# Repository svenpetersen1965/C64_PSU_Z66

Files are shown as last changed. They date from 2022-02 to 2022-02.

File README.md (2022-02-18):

# C64_PSU_Z66
This is a PSU for the Commodore C64 in the Kradex Z66 case. The goal of the development is a budget but capable and reliable PSU for the C64.

This repository contains a full documenation and all project files. The <a href="https://github.com/svenpetersen1965/C64_PSU_Z66/blob/main/Rev.%201/PDF/C64PSU-Z66_Rev1.pdf">documentation</a> can be found in the pdf subdirectory. Read it, please. 

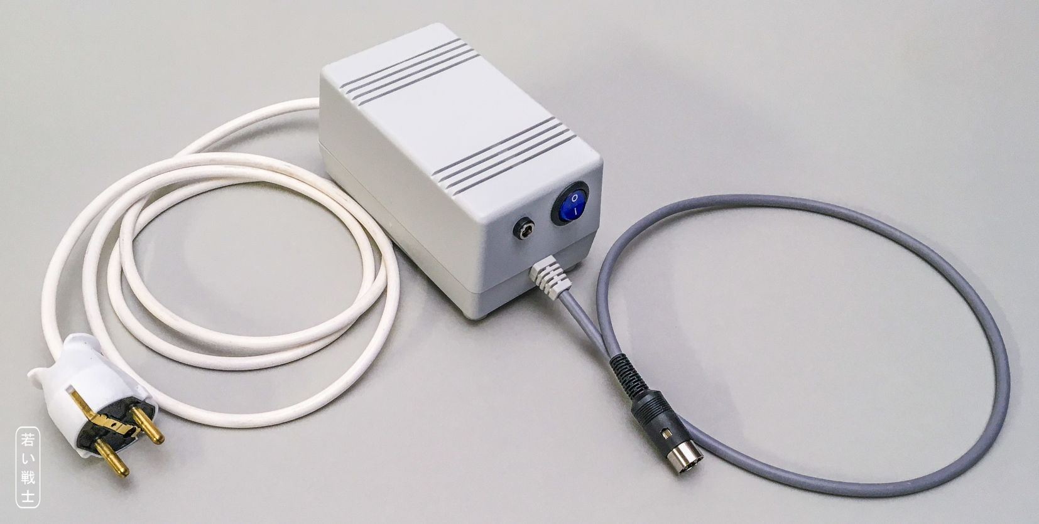
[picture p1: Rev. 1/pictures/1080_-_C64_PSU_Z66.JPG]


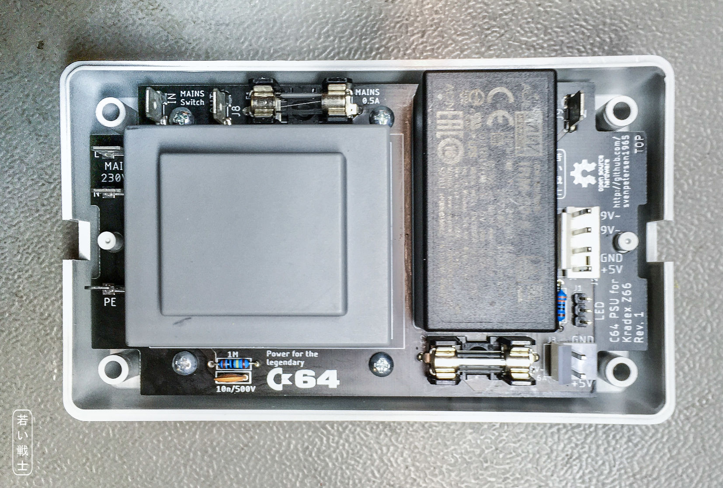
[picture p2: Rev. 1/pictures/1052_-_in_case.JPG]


Learn more about cable making: Please visit my <a href="http://tech.guitarsite.de/cable_making.html">website</a>.

The BOM value of the PSU is 42.16€ (as of February 2022).

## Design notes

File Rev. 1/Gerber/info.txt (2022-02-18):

       
       Board: C64_PSU_Z66
       Rev.:  1
  
       Files:
       ======
  
       All Gerber files are generated in extended gerber format (RS274X)
       *.TOP        : Film top copper
       *.BOT        :  -"- bottom copper
       *.STC        :  -"- top soldermask 
       *.STS        :  -"- bottom soldermask
       *.PLC        :  -"- silk screen top
       *.MIL        : Millings 
       *.DK         : Drills plated Through (Excellon)
       *.NDK        : Drills not plated Through (Excellon)
       *.OUT        : Board outline

       Board Size:
       ===========
       Length     :   123.5 mm
       Width      :   70.0 mm
       Thickness  :   1.6 mm
       Material   :   FR 4
       Copper     :   35 um
       Surface    :   HASL
       
       Remarks:
       ========

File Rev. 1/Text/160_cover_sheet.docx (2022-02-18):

Project Documentation

Commodore C64 PSU for the Kradex Z66 Case

Project number: 160

Revision: 1

Date: 08.02.2022

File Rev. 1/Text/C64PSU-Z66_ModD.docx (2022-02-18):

Commodore C64 PSU for the Kradex Z66 Case Rev. 1

Module Description

# Introduction

The goal of this development is a budget 230V PSU for the Commodore C64 (and VIC-20CR) in a budget case (Kradex Z66) with easy to do cut outs. It is based on a transformer for the 9VAC and an AC/DC module for the +5VDC.


Figure 1: C64 PSU in the Z66 case

There are two options for the transformer:

- BREVE TUFVASSONS: TEZ10/D/9V (10VA/1A fuse)
- Block: VC16/1/9 (16VA/1.6A fuse, not recommended)

It is recommended to use the (cheaper) 10VA type. Since transformers are not regulated, the nominal output voltage is reached at nominal load, below that load, the output voltage is higher. Usually, it is no problem to use a 16VA transformer with the C64, but some of the (oldest) 5 pin/ASSY 326298 boards do not have a heat sink on the linear 5V regulator (7805). Due to the higher output voltage of the transformer, the input of the 7805 is also higher and the regulator tends to overheat (which will first cause video problems). With all other ASSY numbers, even an 18VA transformer does not cause any trouble. The VIC-20 CR (DIN power jack) works well with both transformers. The fuse has to be different for each of the two transformers.

Further on, there are two options for the AC/DC module:

- Mean Well: MPM-10-5 (2A/10W)
- Mean Well: IRM-20-5 (4A/20W)

Both modules have a pretty similar and work well with the C64. The 20W model allows to additionally power a Raspberry Pi/Pi1541 through a barrel connector. The 10W AC/DC module allows to power an additional device like the retroTINK HDMI converter. A USB jack can be installed for this purpose.

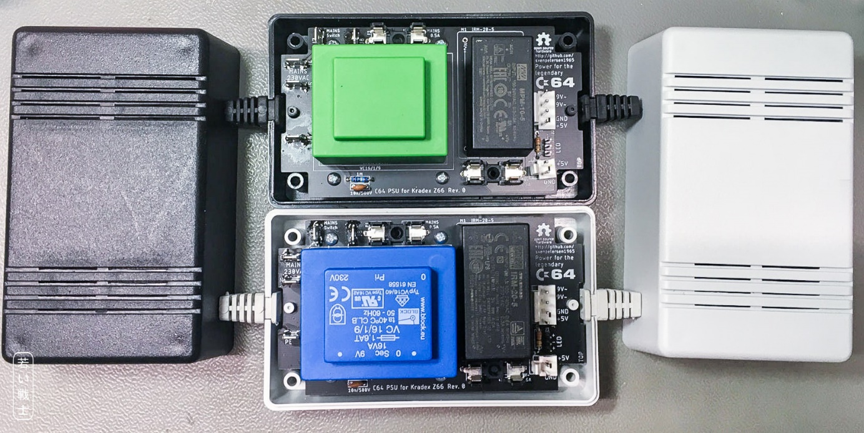
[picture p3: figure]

Figure 2: Both versions of transformer and AC/DC-module (Rev. 0)

# Functional Description

The PSU generates +5VDC and 9VAC from the mains voltage of 230V. The +5VDC is the out voltage of an AC/DC converter M1 or M2. The maximum output current depends on the chosen model of this converter. 2A are sufficient (the original PSU generated max. 1.5A). M1 and M2 have wide range inputs and would be capable of 85VAC to 264VAC mains voltage. The 9VAC are generated with a transformer (TR1 or TR2). Thus, the mains voltage should be close to the 230V nominal primary voltage of the transformer.

The protective earth (PE) of the mains cable is connected to GND via an RC-combination (1MΩ in parallel with 10nF/500V). This is to prevent any mains voltage coupled via a stray capacitance between primary and secondary, which is a very common thing with AC/DC converters and switch mode PSUs in general. It also cancels the coupled mains voltage of any PSU in the system, like the power supply of the monitor, the HDMI converter or a Pi1541 disk drive emulator. It is not (yet) a common feature of Commodore replacement PSUs and definitely worth the investment for a fully wired mains connection and the R and the C.

The PSU has an input fuse (500mA, slow blow), a mains power switch (illuminated). The transformer has an output fuse (1A or 1.6A depending on the model).

Since the AC/DC modules have a short circuit, over voltage, overload and over temperature protection, there is no fuse for the +5V. Further, there should be as little voltage drop between the module and the computer. The 5V is pretty accurate (while the original PSUs have a no-load output voltage of about 5.2V to 5.3V). The voltage-drop over a fuse is quite high (over 100mV, depending on the value of the fuse).

Also, the output cable should be as short as possible (50cm to 70cm are recommended).

The mains switch has an input, an output and the neutral (N). Neutral is only required for illuminated mains switches. The N spade connector on the switch is usually colored differently (e.g. brass, while the other two are silver coated).

There is a connector for a power LED. With an illuminated mains switch, it is not required. The 330Ω resistor R1 is sufficient for red, yellow or green LEDs. Blue and white LEDs are usually “bright enough” with this value. R1 is not required, if no power LED is connected.

Since both AC/DC module have a soft start feature, the 5VDC are slightly delayed against the 9VAC. I have never experienced any problem when the C64 was switched on before the PSU was switched on, the recommended power up sequence is PSU first, C64 second.

# Connectors

## Spade connectors

There are 6 spade connectors (6.3x0.8mm) on the board, which are all connected to mains voltage.

Connector | Function
J4 | 230V mains L (hot)
J5 | 230V mains N (neutral)
J6 | PE (protective earth)
J7 | Mains switch input lead
J8 | Mains switch output lead
J9 | Mains switch N (neutral)

## J1 – Power LED

- Pin header, 1x3 circuits, 2.54mm (0.1”) pitch
- Crimp housing: Dupont crimp housing
- Dupont crimp terminals

It is possible to use a widely available (Ebay, AliExpress etc.) Dupont cable, which can be cut and soldered to the LED.

Pin | Signal
1 | LED +
2 | LED -
3 | LED +

The pin out of this power LED connector is the same like in a C64 and VIC-20.

## J2 – C64 Power Connector

- Molex KK 396 Header, Vertical, Friction Lock, 4 Circuits, Tin (Sn) Plating: P/N 0026604040
- KK 3.96mm Crimp Terminal Housing, Friction Ramp, 4 Circuits, Natural: P/N 09503041
- KK 396 Crimp Terminal 2478, 18-24 AWG, Bag, Brass Tin (Sn): P/N 08500106.

Pin | Signal
1 | +5V
2 | GND
3 | 9VAC2
4 | 9VAC1

## J3 – Auxiliary +5V Connector

- Molex KK 396 Header, Vertical, Friction Lock, 2 Circuits, Tin (Sn) Plating: P/N 0026604020
- KK 3.96mm Crimp Terminal Housing, Friction Ramp, 2 Circuits, Natural: P/N 09503021
- KK 396 Crimp Terminal 2478, 18-24 AWG, Bag, Brass Tin (Sn): P/N 08500106.

Pin | Signal
1 | +5V
2 | GND

## Note

If you want to find a cheaper alternative for the Molex KK 3.96 connector series, the search term on Ali Express is “CH3.96”. Do not mix Molex crimp terminals with CH3.96 housings and vice versa. They do not fit well to each other.

A suitable crimp tool for this kind of connector is e.g., the Engineer PA-20 (1.9/2.3 for wire/insulation crimp) or the IWISS IWS-2820 (the cheaper one - 1.9/2.2 for wire/insulation crimp). Also, the IWISS SN-28B crimp tool produces decent crimps (22-20 notch).

The spade/FastOn connectors require a crimp tool for insulated connectors. The color of the insulation is not matter of taste. It marks the suitable wire gauges. With an AWG20/0.75mm² cable, you need a red insulation (0.5mm²-1.5mm²/AWG21-16). The crimp tool has colored dots below the dedicated notch.

# Cable Making

## Lengths

Cable | Length | Note
Mains | 2 meters, up to your taste | Strip off the (outer) jacket: 8cm, 3xAWG20/0.75mm²
Switch L (in) | 16cm | Brown AWG20/0.75mm²
Switch L (out) | 15cm | brown (or black)
Switch N | 9cm | blue
5V auxiliary | 8cm | AWG20, red and black
Power LED | 10cm | AWG24/0.25mm², red and black
Output | 50cm – 70cm | Strip off the mantle: 6cm, 4xAWG20/0.75mm²

## Mains cable

The mains cable is matter of how long you want it to be. There is no critical length within the range of a few meters. Rather make the mains cable longer and the output cable as short as possible.

The cable jacket (outer insulation) has to be stripped off approximately 8cm. The wire insulation should be stripped off 5mm.

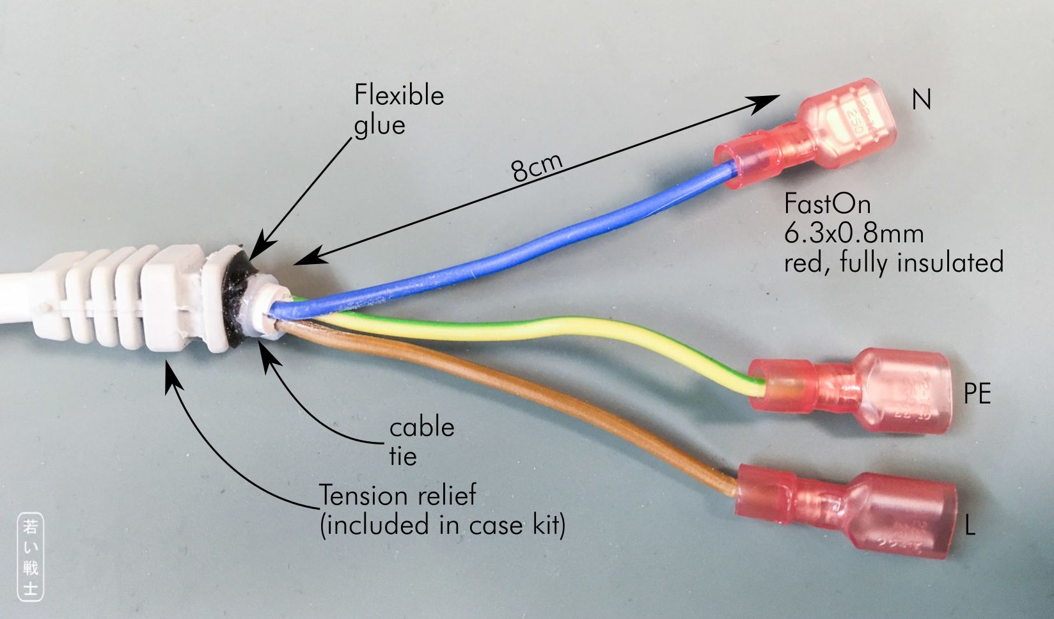
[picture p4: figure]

Figure 3: Mains cable

The case comes with two tension reliefs, one for the input (mains) cable and one for the output cable. This will not hold the cable securely. So additional actions have to be taken. A (small) cable tie works pretty well here. Further, gluing the cable into the tension relief with a flexible (silicon) glue is recommended. An epoxy-based glue does not work.

The FastOn crimps should be carried out well and the crimp needs to be tested (pull test). Better order more FastOn connectors than required in the BOM.

The colors of the (inner) wires are (most common):

Wire | Function
brown | Hot (L)
blue | Neutral (N)
yellow-green | Protective Earth (PE)

Note: if you are not familiar with this already, you should probably not be building this power supply.

## Mains Switch

The mains switch is preferably a round switch with a 20mm mounting hole. Illuminated switches require a 3rd (N) lead, the input and the output tap should not be confused, so the light goes off, when the switch is off (ion case you do not require a night light). Non-illuminated switches only require two leads and are not directional.

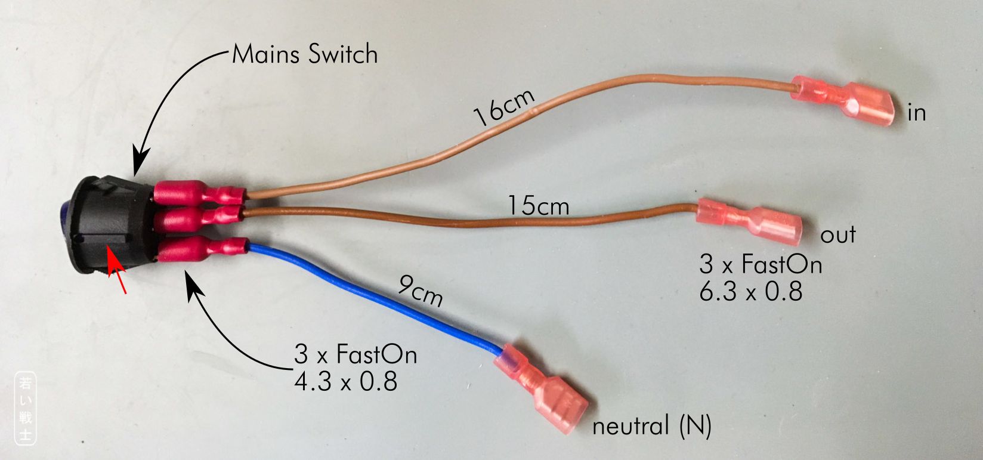
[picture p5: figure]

Figure 4: Mains switch

The anti-twist protection is marked with a red arrow. The N tap is usually marked with a different color. Again, the FastOn crimps should be carried out well and each crimp should be tested.

## Output Cable

The colors of the shown output cable comply with IEC 60757. This does not really matter, but you should choose them in a way, that it can be soldered to the DIN-connector comfortably.

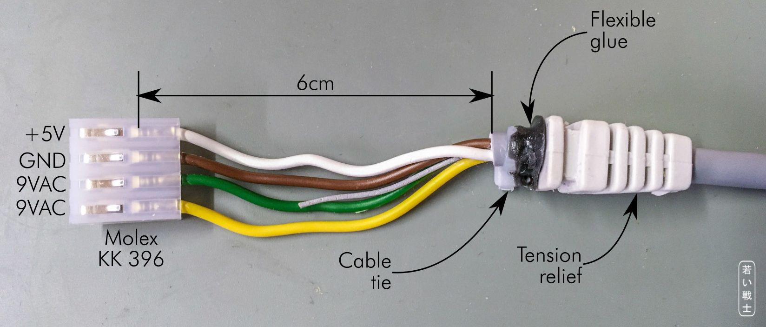
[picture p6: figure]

Figure 5: The output cable

Pin | Function | Color
1 | +5V | white
2 | GND | brown
3 | 9VAC (1) | green
4 | 9VAC (2) | yellow

The other end of the cable is the DIN connector. Make sure, that you do not forget to install the tension relief and the insolation sleeve of the DIN-jack, before you start soldering the cable to the connector. Millions of cables had to be soldered a 2nd time, because one of these items were forgotten to install (in the proper orientation).

There are several methods to solder a DIN-connector, some stick the connector insert into a potato (rich people use an avocado instead). I prefer using the helping hand for the first solder joint, the remaining solder joints can be performed without, since the insert is already attached to the cable. Do not tin the wire strands before inserting them into the solder cups of the pins. The connectors with half solder cups are easiest to solder. Flux is a great invention and definitely helpful when soldering the DIN connector.

The following table shows the pin out of the C64 (and VIC-20 CR).

C64 Power Jack | Pin | Voltage
| 1 | -
| 2 | GND
| 3 | -
| 4 | -
| 5 | +5V
| 6 | 9VAC(1)
| 7 | 9VAC(2)

Table 1: Power jack of the C64

The 9VAC leads can be swapped if required. It is AC, so the polarity does not matter.

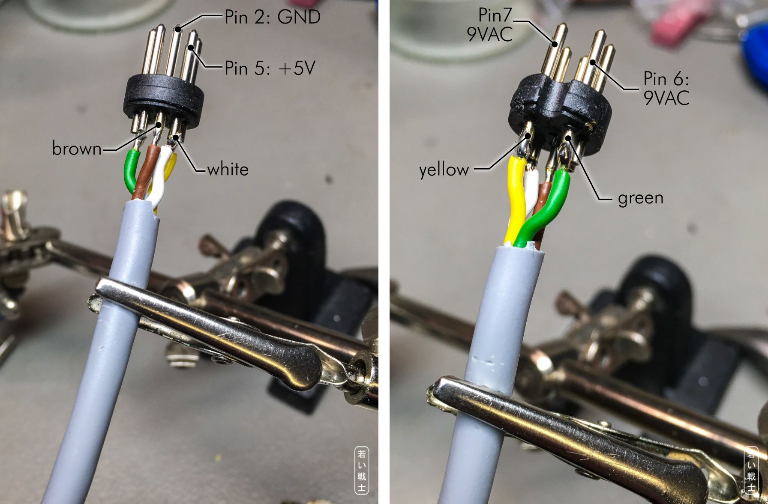
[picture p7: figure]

Figure 6: Soldering the DIN-plug (output cable)

## Auxiliary 5V cable (optional)

The auxiliary 5V cable is optional. It makes use of the power reserve of the AC/DC module.

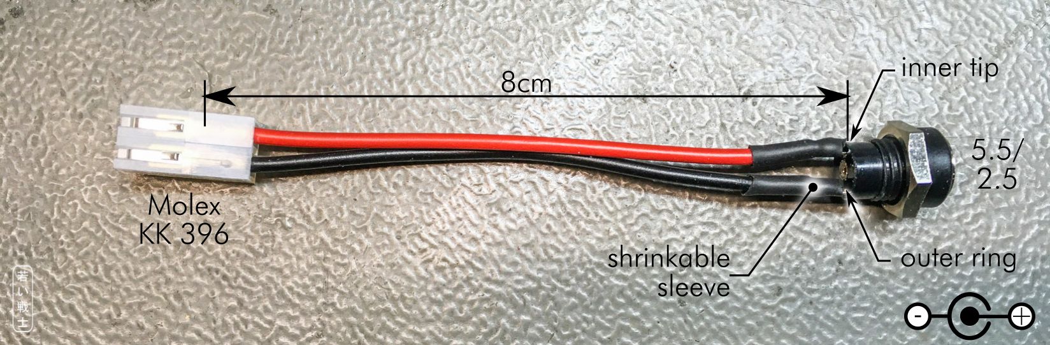
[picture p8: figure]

Figure 7: Auxiliary 5V cable (optional)

It might be good not to install the crimp housing before the cable is installed in the case. The crimp terminals can pass the drill in the case, the housing of the connector does not. The terminals can be removed from the housing, but it is better to avoid this work.

## USB-Port (optional)

Alternatively to the barrel jack, a USB jack can be installed to provide auxiliary 5V. This is the choice, if an additional device with a (micro) USB port should be powered. The USB connector is harvested from a slot bracket.

The +5V of the USB-cable is usually a red wire, the GND is the black wire. The data wires are white and green.

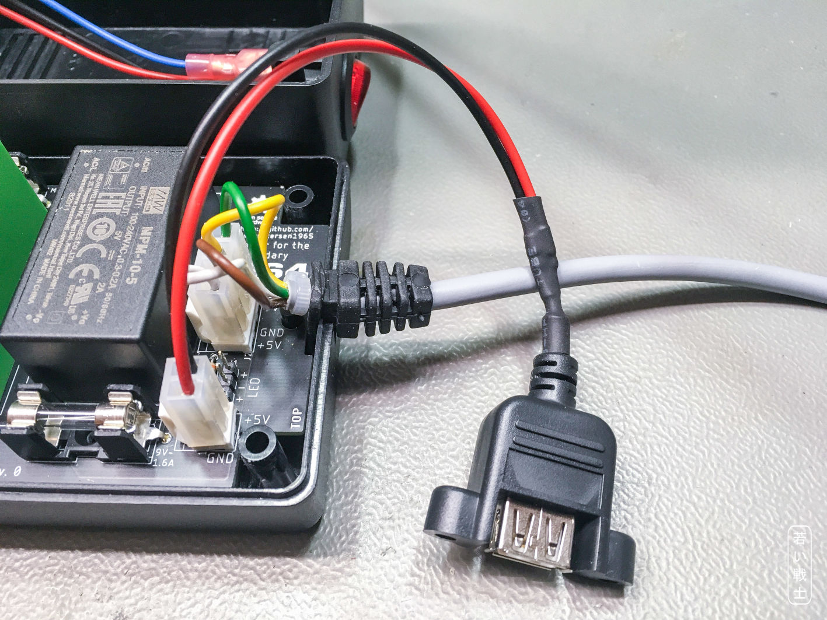
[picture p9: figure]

Figure 8: USB-Port (optional)

The cable making is a bit harder - the cutout is more complicated, too. It is a matter of taste, if this more complicated cable is installed or a standard USB cable is modified with a barrel plug to power a device like mentioned before.

## LED-Cable (optional)

The power LED is optional. Usually, it is not required in case the mains switch is illuminated.

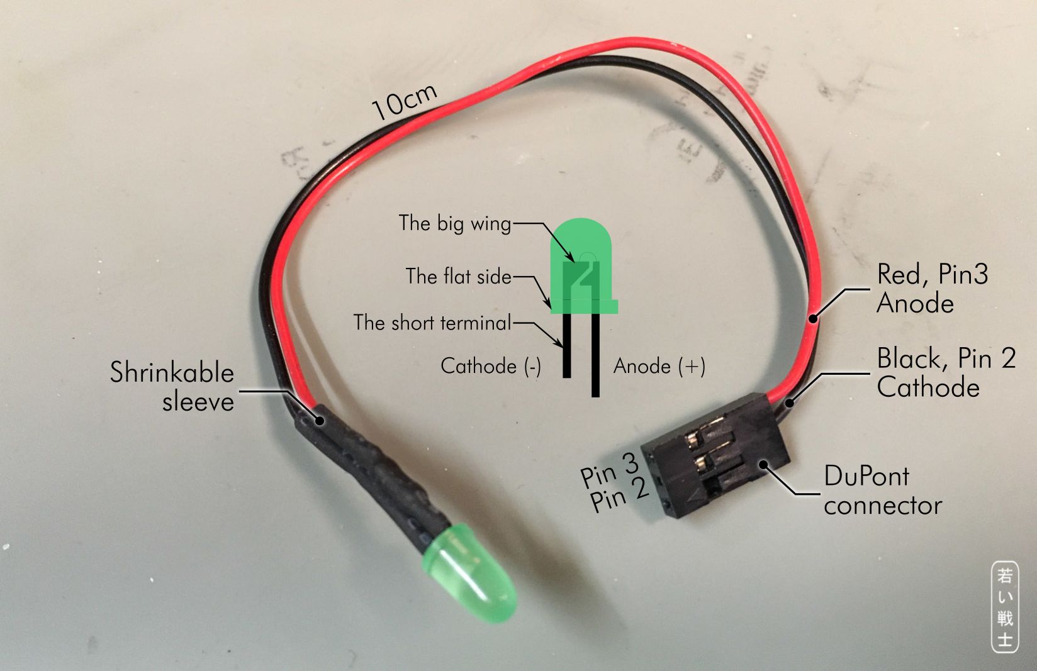
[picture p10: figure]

Figure 9: Power LED (optional)

Note:
For crimping the DuPont terminal, the Engineer PA-20 (1.6/1.6 for wire/insulation crimp) or the IWISS IWS-2820 (the cheaper one - 1.6/1.6 for wire/insulation crimp) is a working choice. The IWISS SN-025 might be the most suitable tool.

# Installation in the Z66 Case

There are only a few cutouts in the case.

1. Mains switch
2. Auxiliary +5V/barrel connector (optional)
3. USB port for auxiliary 5V (optional)
4. Power LED

The mains switch is primarily a 20mm drill and a notch for the anti-twist protection. The auxiliary 5V barrel connector is just a round hole. The diameter depends on the type of connector used for this. It can be measured with a caliper.

There are 1:1 scaled drawings, which can be printed out (in the original scale), cut out, then positioned and fixed to the case. The centers of the holes can be marked with a needle (after that, with a center punch). Also, the corners of the anti-twist notch of the mains connector.

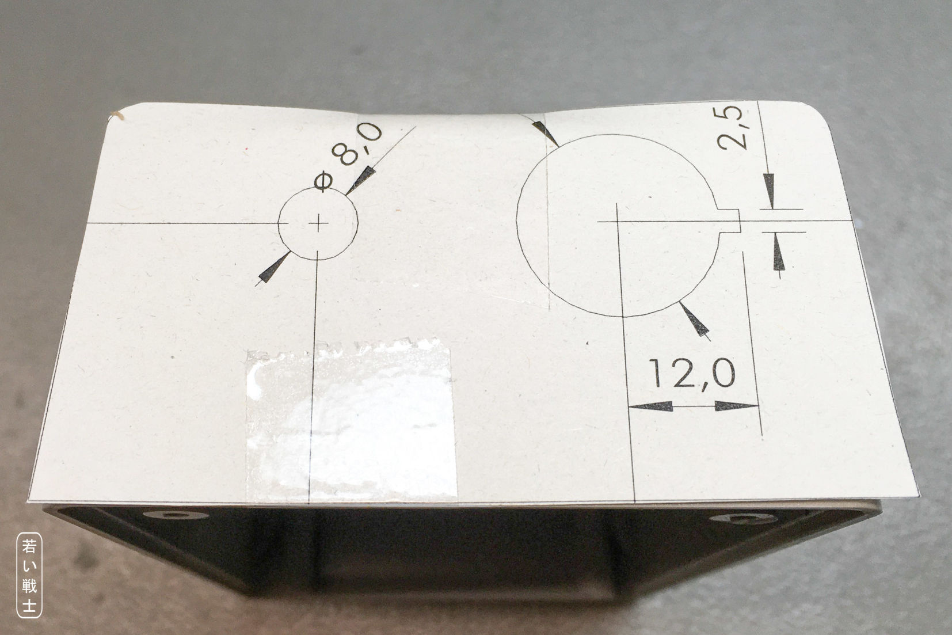
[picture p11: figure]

Figure 10: Marking the case with the drawing

The cutout drawing fits better on the case, than it looks in Figure 10, the appearance is matter of the used lens and the proximity. An accuracy of about +/- 0.5mm for the positioning of the paper is suitable. The center of the holes and the corners of the notch can be marked with a needle, first. A center punch only might not the accurate enough.

The 20mm hole for the mains switch is first started with a 4mm drill, which is the smallest diameter of my step drill. Just drill this with a normal drill. Then use the step drill to obtain a 20mm hole.

The notch for the anti-twist protection is then filed with a small square file. Do not file the notch too deep, it would become visible even after the switch is installed.

The diameter of the hole for the barrel connector is not necessarily 8mm, it depends on the connector type.

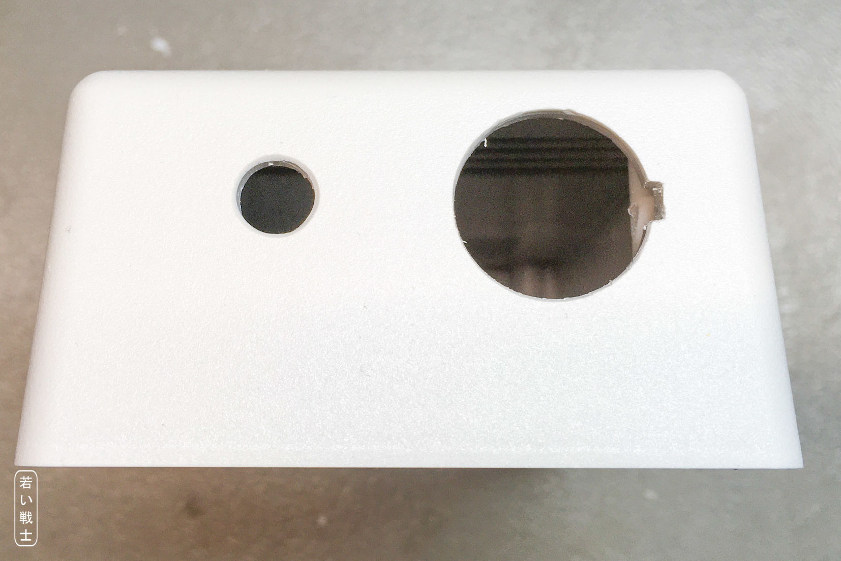
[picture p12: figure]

Figure 11: The top shell after drilling

If a power LED is desired, a hole, that fits the LED holder needs to be drilled. The top side might be a good place, a central position close to the front edge is suggested.

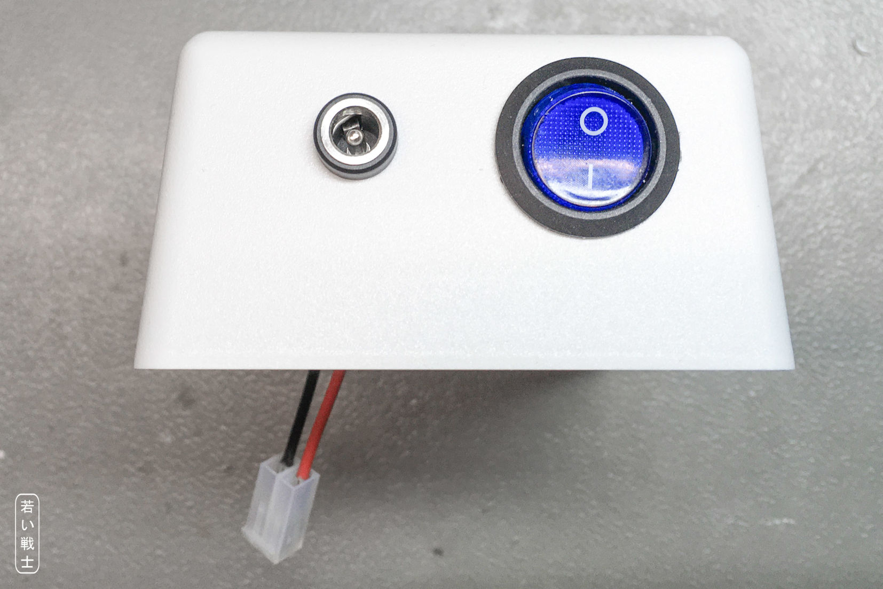
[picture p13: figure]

Figure 12: The top shell with the switch and the auxiliary barrel connector installed

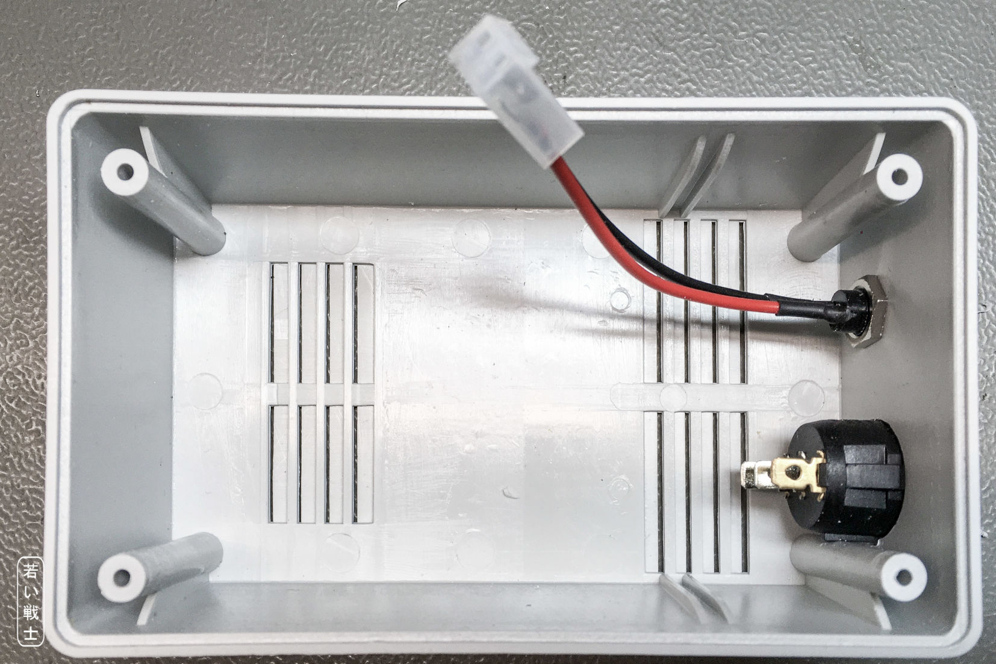
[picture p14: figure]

Figure 13: Top shell, bottom view

There is another drawing for the USB port cutout, which can be used as a template. The connector is positioned in a way, that it fits above the AC/DC module.

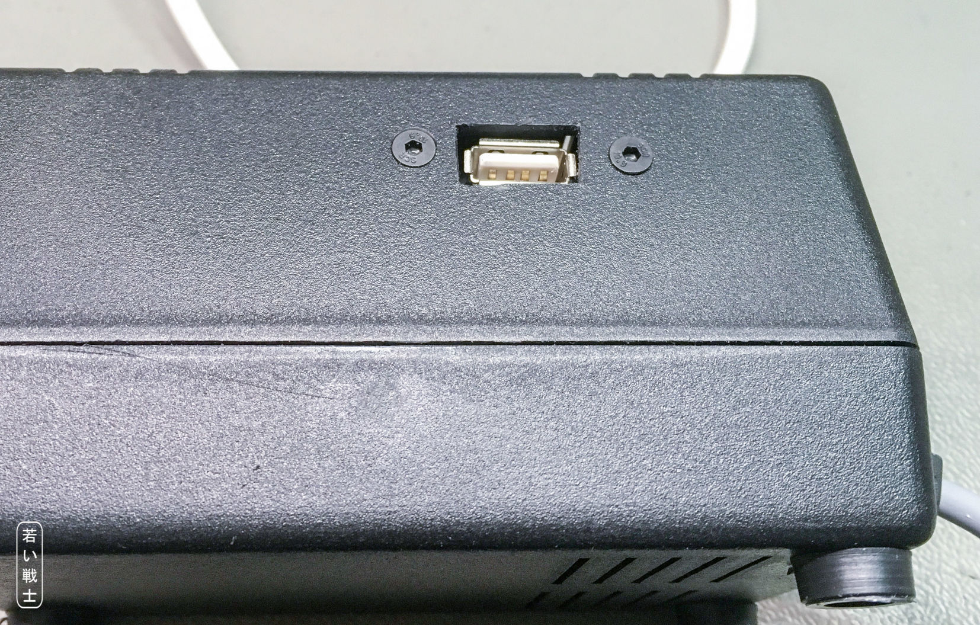
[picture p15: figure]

Figure 14: The USB port on the left side of the top shell

The USB connector is screwed to the top shell with two screws (M3). In Figure 14 these are countersunk. Black screws might fit better to a black case, for a light grey case, normal coated screws are a good choice.

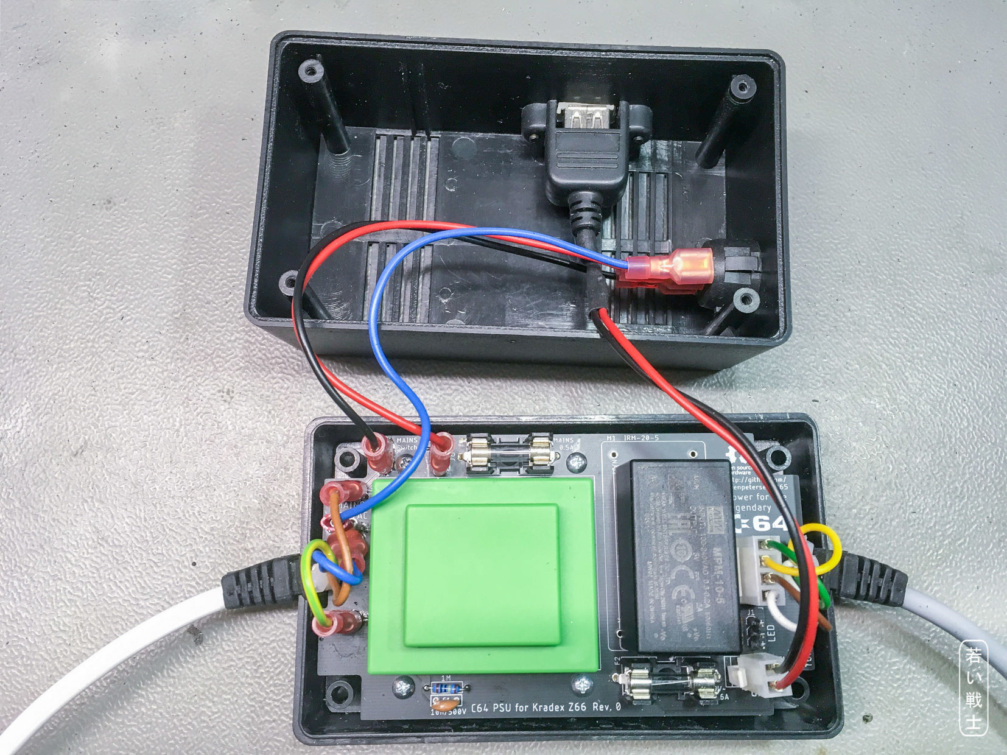
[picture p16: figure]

Figure 15: USB cable installed on a Rev. 0 board

## Testing

Before connected to the real computer, it is strictly advised to check the polarity of the +5V and GND on the DIN-Connector. Refer to Table 1: Power jack of the C64. A good way for testing the DIN connector is to connect it to a DIN jack.

In case you need to test C64 PSUs more often, this is a good thing to have.

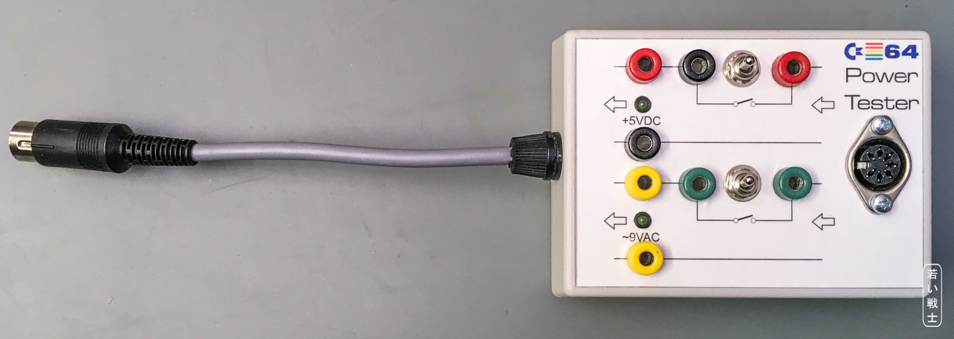
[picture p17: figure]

Figure 16: The C64 PSU tester

It is of course not required to have such a test device for building one power supply. The pictures are just put in here as an inspiration. The 4mm lab jacks allow to connect multimeters and load resistors (or an electronic load, if you have one).

Some of the old PSUs have the +5V connected to Pin 4, which is the reason for the 2nd red wire in Figure 17.

The LED for the 9VAC require an anti parallel protection diode. They are not capable of much more than 4V reverse voltage and would get destroyed by the AC.

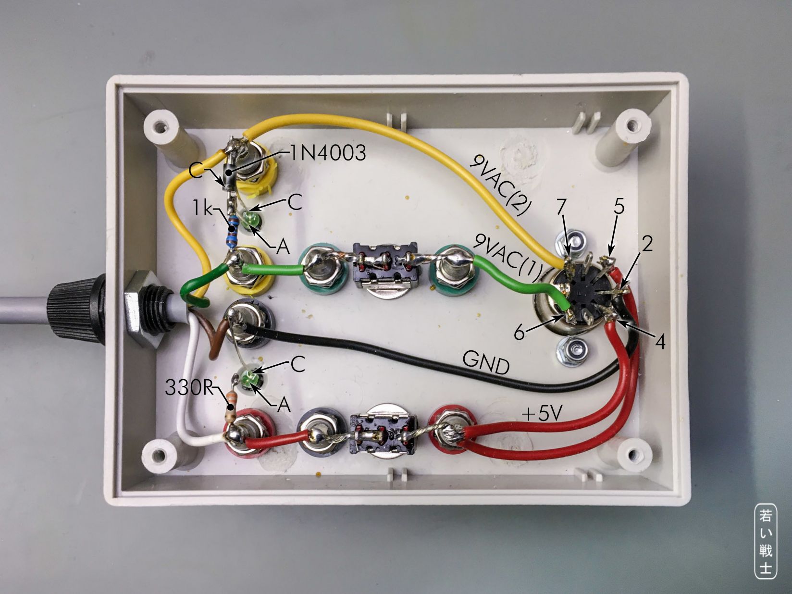
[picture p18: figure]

Figure 17: The C64 PSU tester (inside)

# Dimensions

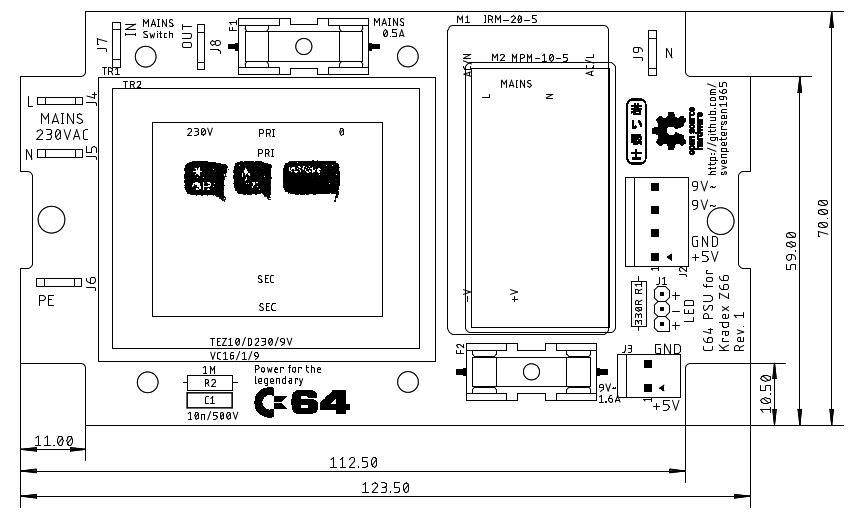
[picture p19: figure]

Figure 18: Dimensions of the PCB (not scaled)

# Revision History

## Rev. 0

- Fully functional prototype

## Rev. 1

- FastOn J9 added as N connector for illuminated power switches

C64PSU-Z66_ModD.docx 18.02.2022 20:13 Drafted by Sven Petersen Page 2 of 2 Doc.-No.: 160-6-01-01

C64PSU-Z66_ModD.docx 18.02.2022 20:13 Drafted by Sven Petersen Page 1 of 1 Doc.-No.: 000-6-00-00

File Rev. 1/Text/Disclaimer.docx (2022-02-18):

Disclaimer

Working with mains voltages can be harmful and cause death. Do not connect this PCB to mains (230VAC) unless you are trained in doing so and know the required safety regulations.

This PSU is a prototype, it is not certified in any way and might only be used as a prototype under laboratory conditions. Usage is at own risk. Do not leave unattended while powered on or connected to mains.

The PSU is designed to be installed in a plastic case. A 3 prong mains connector (with protective earth PE is recommended, though).

The documentation is drafted to the best of my knowledge. The creator is not liable for the accuracy and completeness.

Disclaimer.docx 08.02.2022 17:45 Erstellt von Sven Petersen Seite 2 von 2 Dok.-Nr.: 000-8-00-00

Disclaimer.docx 08.02.2022 17:45 Drafted by Sven Petersen Page 1 of 1

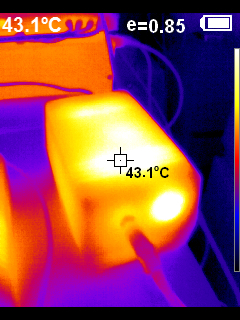
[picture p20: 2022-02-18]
Rev. 1/pictures/20220217-194722_FLIR_outside_9h.jpg

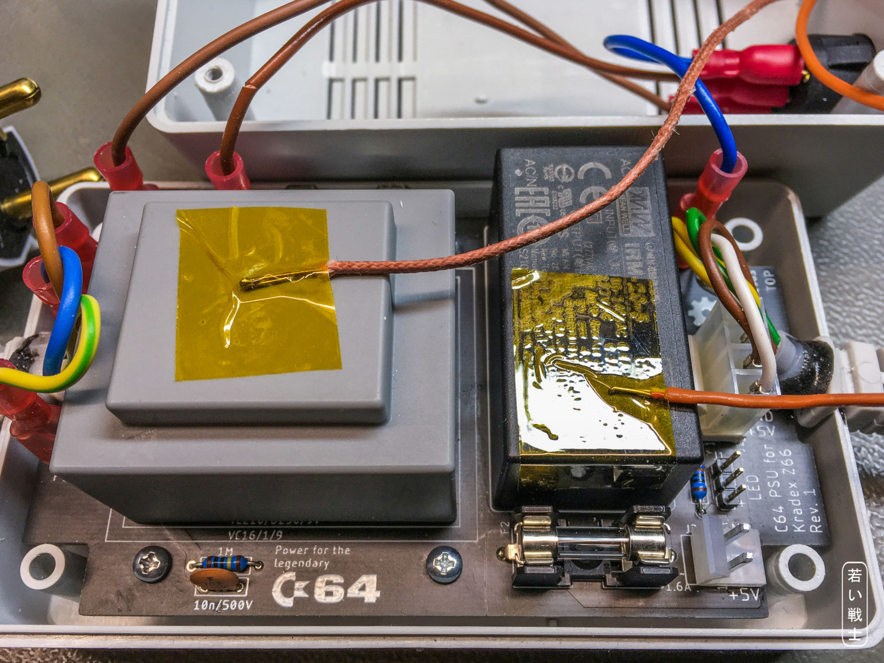
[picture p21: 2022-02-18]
Rev. 1/pictures/1163_-_thermal_1st_configuration.JPG

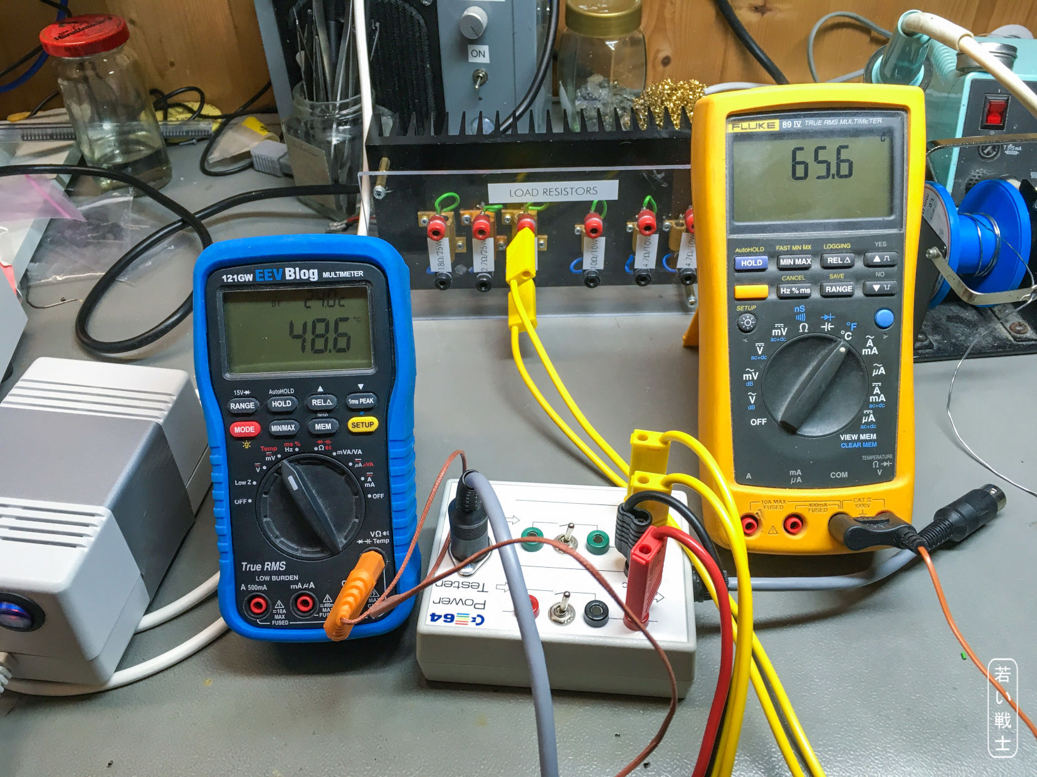
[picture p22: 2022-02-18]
Rev. 1/pictures/1185_-_thermal_final_reading_10VA.JPG

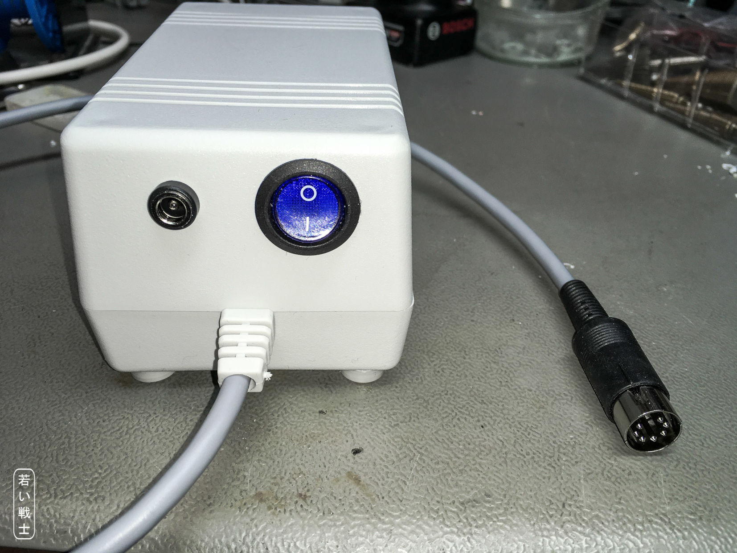
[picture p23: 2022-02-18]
Rev. 1/pictures/1065_-_front_view.JPG

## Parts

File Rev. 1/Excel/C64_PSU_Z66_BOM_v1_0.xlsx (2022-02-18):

C64 PSU "Z66" Rev. 1
Bill of Material Rev. 1.0
Pos. | Qty | Value | Footprint | Ref.-No. | Comment
1 | 1 | 160-2-01-01 | 2 Layer | PCB Rev. 1 | 2 layer, Cu 35µ, HASL, 123.5 x 70.0mm, 1.6mm FR4
2 | 6 | 6.3 x 0.8 | FLA6,3 | J4, J5, J6, J7, J8, J9 | Spade connector f. PCB, e.g. Reichelt VT FS-P 6,35
3 | 1 | Pin header 1x3, 2.54mm | 1X03 | J1 | e.g. MPE Garry 087-1-003, Reichelt MPE 087-1-003
4 | 1 | dupont housing, 3p |  | (J1) | ebay, AliExpress or other (optional: for power LED)
5 | 2 | dupont terminals, female |  | (J1) | ebay, AliExpress or other (optional: for power LED)
6 | 1 | Power LED + LED holder |  | (J1) | red, yellow, green, blue (optional)
7 | 1 | 26604020 | SPOX_3.96_2P | J3 | optional (+5V tap): Molex SPOX, e.G. Reichelt: MOLEX 26604020, tme.eu: MX-26-60-4020
8 | 1 | 09503021 |  | (J3) | crimp housing, optional (for +5V tap): Molex. E.g. Reichelt: MOLEX 9503021, tme.eu: MX-2139-2A
9 | 2 | 08500106 |  | (J3) | crimp terminal, optional (for +5V tap), Molex. E.g. Reichelt: MOLEX 08500106, tme.eu: MX-2478-1-P913L (= 10 pack)
10 | 1 | 26604040 | SPOX_3.96_4P | J2 | Molex SPOX, e.G. Reichelt: MOLEX 26604040, tme.eu: MX-26-60-4040
11 | 1 | 09503041 |  | (J2) | crimp housing: Molex. E.g. Reichelt: MOLEX 9503041, tme.eu: MX-2139-4A
12 | 4 | 08500106 |  | (J2) | crimp terminal, Molex. E.g. Reichelt: MOLEX 08500106, tme.eu: MX-2478-1-P913L (= 10 pack)
13 | 2 | 0031.8211 | 318211 | F1, F2 | Schurter fuse holder (5x20mm). E.g. Reichelt: PL OGN-25, tme.eu: 0031.8211
14 | 1 | 0.5A slow blow | 20x5mm | (F1) | Mains fuse
15 | 1 | 1.6A slow blow | 20x5mm | (F2) | option: Fuse for 9VAC (for VC16/1/9 transformer)
16 | 1 | 1.0A slow blow | 20x5mm | (F2) | option: Fuse for 9VAC (for TEZ10/D230/9V transformer)
17 | 1 | 10n/500V | C-5 | C1 | Ceramic Cap, 500V, pitch 5mm, Reichelt: KERKO-500 10N, tme.eu: CCH-10K (=10 pack)
18 | 1 | 1M | R-10 | R2 | Resistor, metal film, 5% or better, 0,6W
19 | 1 | 330R | R-10 | R1 | Resistor, metal film, 5% or better, 0,6W
20 | 1 | IRM-20-5 | IRM-5-20 | M1 | Mean Well. Reichelt IRM-20-5, tme.eu: IRM-20-5 (4A)
21 | 1 | MPM-10-5 | MPM10 | M2 | alternative for M1: Mean Well. Tme.eu: MPM-10-5 (2A)
22 | 1 | TEZ10/D230/9V | TEZ10 | TR2 | BREVE TUFVASSONS transformer, alternative for TR1, tme.eu: TEZ10/D/9V. Recommended type.
23 | 1 | VC16/1/9 | VC16/1/9 | TR1 | alternative for TR2: BLOCK transformer, Reichelt: EI 54/18,8 109 not recommended!
24 | 10cm | AWG24/0.25mm², red |  |  | Cable for Power LED (option)
25 | 10cm | AWG24/0.25mm², black |  |  | Cable for Power LED (option)
26 | 3cm | 2.4/1.2mm |  |  | shrinkable sleve, shrink ration 1:2 (power LED)
27 | 10cm | AWG21/0.5mm², red |  |  | Cable for +5V tap (option)
28 | 10cm | AWG21/0.5mm², black |  |  | Cable for +5V tap (option)
29 | 1 | Connector (barrel jack, 5.5/2.5) |  |  | Connector for +5V tap (option), e.g. Reichelt: HEBL 25
30 | 1 | mains cable, 3x0.75mm² |  |  | Mains cable (3 wire recommended), AWG 20
31 | 1 | MAS 70S |  |  | Hirschmann DIN plug 7pin, 262°. Reichelt: MAS 70S, tme.eu: MAS70SGR. Example for C64 power plug
32 | 0.5m | 4x0.5mm² |  | (J2) | Cable for output voltages. 4xAWG21
33 | 6 | 2-520184-2 |  | (J4), (J5), (J6), (J7), (J8), (J9) | TE connectivity, tme.eu: 2-520184-2 or Reichelt RND 465-00067. Example for 6.3 x 0.8 spade terminals, red, fully isolated. Required to connect to the mains connector and switch.
34 | 3 | FastOn connector 4.8x0.8, red, fully isolated |  |  | FastOn for power switch
34 | 30cm | AWG20/0.75mm², black |  |  | Cable for Power Switch
35 | 1 | 1858.1103 |  |  | option for rectangular Power switch: Marquardt 1858.1103, Reichelt: WIPPE 1858.1103, tme.eu: 1858.1103 or other
36 | 1 | R13112BBR3 |  |  | Recommended Power switch (round, 20mm): Bulgin, tme.eu: AE-R13112BNAA, Reichelt: WS R13-112 BNAB
37 | 1 | Kradex Z66 |  |  | Kradex Case, tme.eu. Black: Z66-ABS, Grey: Z66J-ABS
38 | 4 | screws C2.9x6.5mm |  |  | self tapping screws, e.g. DIN 7981
39 | 2 | small cable ties |  |  | e.g. 102x2.5mm (Reichelt KAB 100-2,5)

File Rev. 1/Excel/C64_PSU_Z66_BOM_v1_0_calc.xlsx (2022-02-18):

C64 PSU "Z66" Rev. 1
Bill of Material Rev. 1.0
Pos. | Qty | Value | €/ea | € (total) | Comment
1 | 1 | 160-2-01-01 | 2.00 € | 2.00 € | 2 layer, Cu 35µ, HASL, 123.5 x 70.0mm, 1.6mm FR4
2 | 6 | 6.3 x 0.8 | 0.05 € | 0.30 € | Spade connector f. PCB, e.g. Reichelt RND 465-00018 (100ea)
3 | 1 | pin header 1x3, 2.54mm | 0.08 € | 0.08 € | ebay, AliExpress or other (optional: for power LED)
4 | 1 | dupont housing, 3p | 0.10 € | 0.10 € | ebay, AliExpress or other (optional: for power LED)
5 | 2 | dupont terminals, female | 0.05 € | 0.10 € | ebay, AliExpress or other (optional: for power LED)
6 | 1 | Power LED + LED holder | 0.45 € | 0.45 € | red, yellow, green, blue (optional)
7 | 1 | 26604020 | 0.36 € | 0.36 € | optional (+5V tap): Molex SPOX, e.G. Reichelt: MOLEX 26604020, tme.eu: MX-26-60-4020
8 | 1 | 09503021 | 0.14 € | 0.14 € | crimp housing, optional (for +5V tap): Molex. E.g. Reichelt: MOLEX 9503021, tme.eu: MX-2139-2A
9 | 2 | 08500106 | 0.11 € | 0.22 € | crimp terminal, optional (for +5V tap), Molex. E.g. Reichelt: MOLEX 08500106, tme.eu: MX-2478-1-P913L (= 10 pack)
10 | 1 | 26604040 | 0.54 € | 0.54 € | Molex SPOX, e.G. Reichelt: MOLEX 26604040, tme.eu: MX-26-60-4040
11 | 1 | 09503041 | 0.22 € | 0.22 € | crimp housing: Molex. E.g. Reichelt: MOLEX 9503041, tme.eu: MX-2139-4A
12 | 4 | 08500106 | 0.11 € | 0.44 € | crimp terminal, Molex. E.g. Reichelt: MOLEX 08500106, tme.eu: MX-2478-1-P913L (= 10 pack)
13 | 2 | 0031.8211 | 0.93 € | 1.86 € | Schurter fuse holder (5x20mm). E.g. Reichelt: PL OGN-25, tme.eu: 0031.8211
14 | 1 | 0.5A slow blow | 0.30 € | 0.30 € | Mains fuse
15 | 1 | 1.6A slow blow | 0.30 € | 0.30 € | option: Fuse for 9VAC (for VC16/1/9 transformer)
16 | 1 | 1.0A slow blow | 0.30 € | 0.30 € | option: Fuse for 9VAC (for TEZ10/D230/9V transformer)
17 | 1 | 10n/500V | 0.20 € | 0.20 € | Ceramic Cap, 500V, pitch 5mm, Reichelt: KERKO-500 10N, tme.eu: CCH-10K (=10 pack)
18 | 1 | 1M | 0.10 € | 0.10 € | Resistor, metal film, 5% or better, 0,6W
19 | 1 | 330R | 0.10 € | 0.10 € | Resistor, metal film, 5% or better, 0,6W
20 | 1 | IRM-20-5 | 10.25 € | 10.25 € | Mean Well. Reichelt IRM-20-5, tme.eu: IRM-20-5 (4A)
21 | 0 | MPM-10-5 | 11.78 € | 0.00 € | alternative for M1: Mean Well. Tme.eu: MPM-10-5 (2A)
22 | 1 | TEZ10/D230/9V | 7.43 € | 7.43 € | BREVE TUFVASSONS transformer, alternative for TR1, tme.eu: TEZ10/D/9V. Recommended type.
23 | 0 | VC16/1/9 | 8.95 € | 0.00 € | alternative for TR2: BLOCK transformer, Reichelt: EI 54/18,8 109
24 | 1 | AWG24/0.25mm², red | 0.05 € | 0.05 € | Cable for Power LED (option)
25 | 1 | AWG24/0.25mm², black | 0.05 € | 0.05 € | Cable for Power LED (option)
26 | 1 | 2.4/1.2mm | 0.05 € | 0.05 € | shrinkable sleve, shrink ration 1:2 (power LED)
27 | 1 | AWG21/0.5mm², red | 0.05 € | 0.05 € | Cable for +5V tap (option)
28 | 1 | AWG21/0.5mm², black | 0.05 € | 0.05 € | Cable for +5V tap (option)
29 | 1 | Connector (barrel jack, 5.5/2.5) | 0.69 € | 0.69 € | Connector for +5V tap (option), e.g. Reichelt: HEBL 25
30 | 1 | mains cable, 3x0.75mm² | 3.69 € | 3.69 € | Mains cable (3 wire recommended), AWG 20
31 | 1 | MAS 70S | 0.65 € | 0.65 € | Hirschmann DIN plug 7pin, 262°. Reichelt: MAS 70S, tme.eu: MAS70SGR. Example for C64 power plug
32 | 1 | 4x0.5mm² | 1.70 € | 1.70 € | Cable for output voltages. 4xAWG21
33 | 6 | 2-520184-2 | 0.06 € | 0.36 € | TE connectivity, tme.eu: 2-520184-2 or Reichelt RND 465-00067. Example for 6.3 x 0.8 spade terminals, red, fully isolated. Required to connect to the mains connector and switch.
34 | 3 | FastOn connector 4.8x0.8, red, fully isolated | 0.12 € | 0.36 € | FastOn for power switch
34 | 1 | AWG20/0.75mm², black | 0.05 € | 0.05 € | Cable for Power Switch
35 | 1 | 1858.1103 | 2.13 € | 2.13 € | option for rectangular Power switch: Marquardt 1858.1103, Reichelt: WIPPE 1858.1103, tme.eu: 1858.1103 or other
36 | 1 | R13112BBR3 | 2.96 € | 2.96 € | Recommended Power switch (round, 20mm): Bulgin, tme.eu: AE-R13112BNAA, Reichelt: WS R13-112 BNAB
37 | 1 | Kradex Z66 | 3.31 € | 3.31 € | Kradex Case, tme.eu. Black: Z66-ABS, Grey: Z66J-ABS
38 | 4 | screws C2.9x6.5mm | 0.05 € | 0.20 € | self tapping screws, e.g. DIN 7981
39 | 2 | small cable ties | 0.01 € | 0.02 € | e.g. 102x2.5mm (Reichelt KAB 100-2,5)
40
41 |  |  | Total | 42.16 €

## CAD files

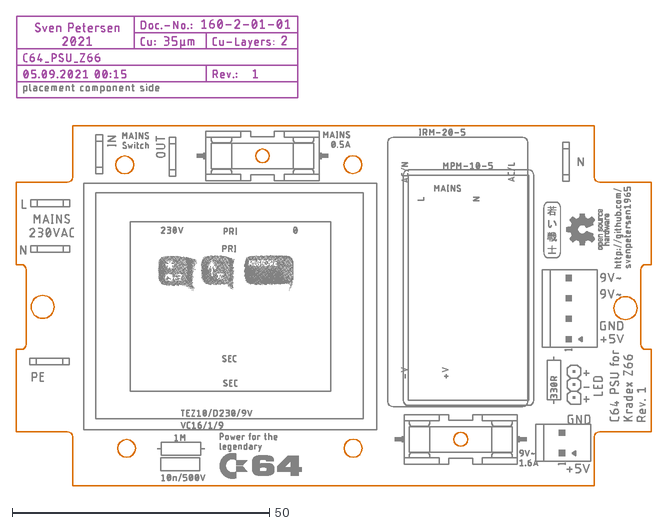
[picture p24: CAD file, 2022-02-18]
Rev. 1/dxf/C64_PSU_Z66.dxf
123.5 x 91.3

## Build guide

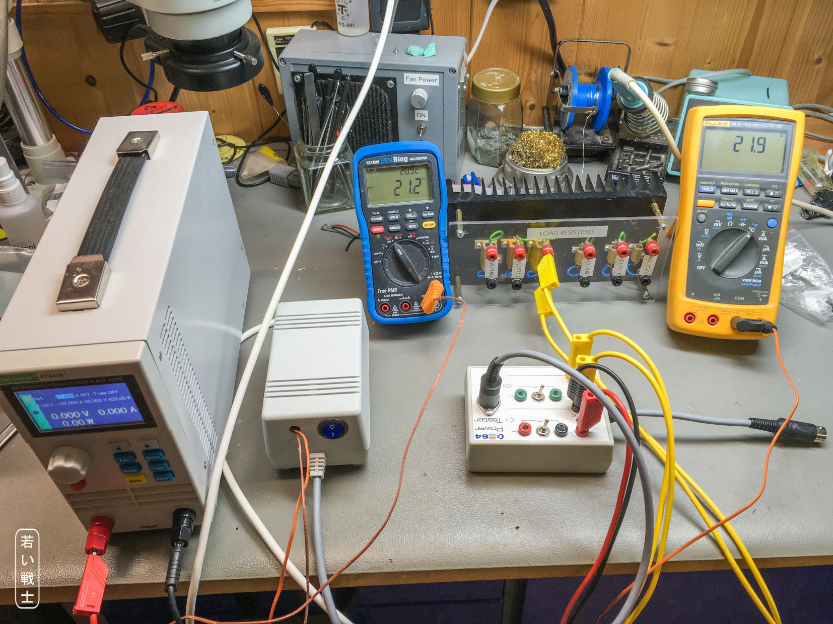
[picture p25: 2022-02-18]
Rev. 1/pictures/1164_-_thermal_1st_setup.JPG

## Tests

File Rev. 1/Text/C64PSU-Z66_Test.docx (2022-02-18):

Commodore C64 PSU for the Kradex Z66 Case Rev. 1

Testing

# 1. Test Setup

## 1.1. Test Equipment

- Multimeter EEVblog 121GW (voltage, temperature)
- Multimeter Fluke 89 IV (current, temperature)
- Electronic Load East Tester ET5410
- Rigol MSO4024 oscilloscope
- Load Resistors (nominal 2.7Ω/25W, 2x4.7Ω/10W, 10Ω/25W, 18Ω/25W)
- C64 Power Tester (DIY, described in the module description)
- C64 S/N WG A 22471 (ASSY 250407), Ultimate II+, video equipment
- FLIR camera: Hti HT-19
- Thermometer: UNI-T UT320D

## 1.2. Devices under Test (DUT)

1. Prototype Rev. 0 (AC/DC IRM-20-5, transformer VC 16/1/9)
2. Prototype Rev. 0 (AC/DC MPM-10-5, transformer TEZ10/D230/9V)
3. Prototype Rev. 1 (AC/DC IRM-20-5, transformer TEZ10/D230/9V)

Since the difference between Rev. 0 and Rev. 1 is only one spade connector for the illuminated power switch, it can be considered equal for testing.

# 2. Test Execution

## 2.1. 5VDC Load Test

The DC voltage under different load conditions were measured with the 121GW multimeter. The PSU was connected to the C64 Power Tester, the load was simulated with the electronic load. A good approximation of a “C64 load” on 5V is about 850mA. The different ASSY numbers have a different power dissipation. It is about 830mA for ASSY 250407 and 250425, while it is 730mA on ASSY 250469.

### 2.1.1. IRM-20-5

IOUT | UOUT
0.00A | 5.03V
0.85A | 4.88V
1.50A | 4.79V

### 2.1.2. MPM-10-5

IOUT | UOUT
0.00A | 5.00V
0.85A | 4.89V
1.50A | 4.80V

## 2.2. 5VDC Ripple Test

The 5VDC were loaded with a 4.7Ω/10W load resistor. The electronic load was not used to prevent any influence of it on the measurement (Figure 1). An oscilloscope was connected to the 5V and set to AC mode, 5us/div.

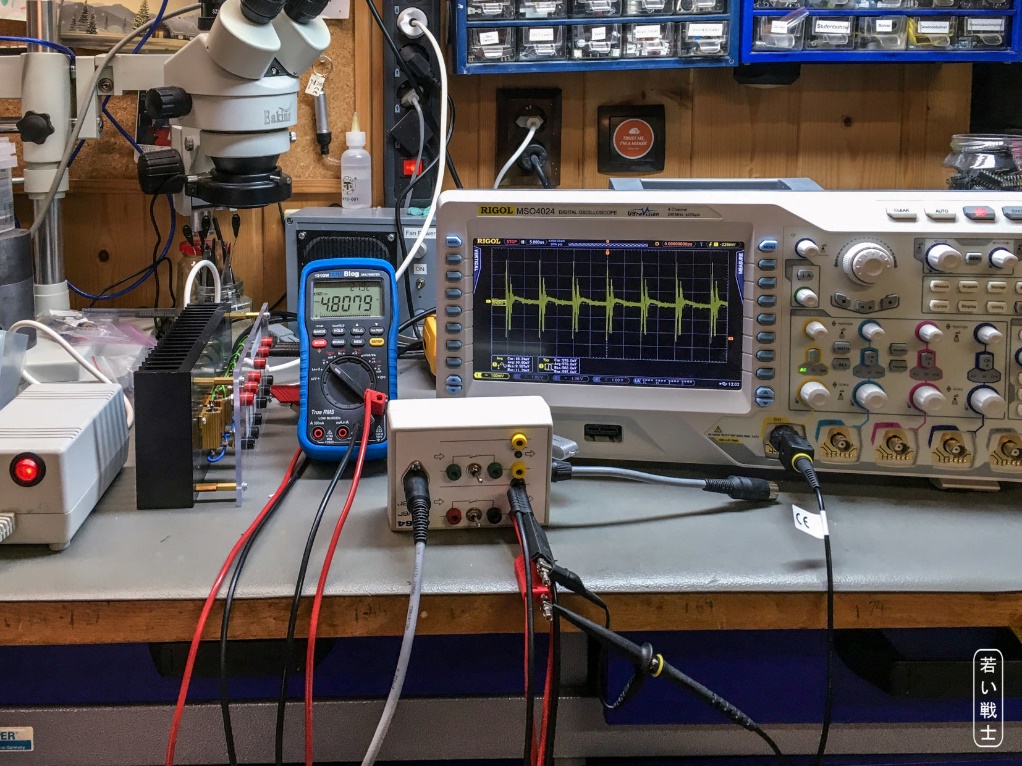
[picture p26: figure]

Figure 1: Setup for the ripple test

#### 2.2.1. IRM-20-5

The vertical setting is 100mV. The ripple is 578.8mVpp and 60.52mVRMS.

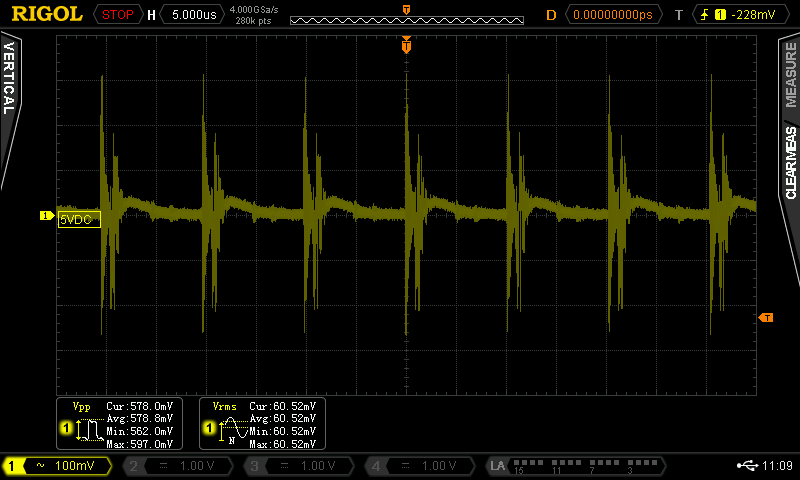
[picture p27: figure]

Figure 2: IRM-20-5 ripple

### 2.2.2. MPM-10-5

The vertical setting is 20mV. The ripple is 85.31mVpp and 17.18mVRMS.

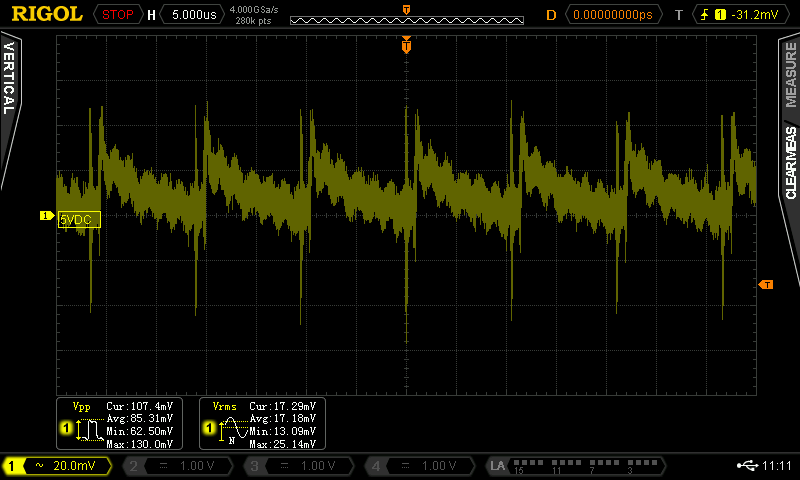
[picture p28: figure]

Figure 3: MPM-10-5 ripple

## 2.3. 9VAC – Transformer Test

### 2.3.1. Procedure

1. Two different DUTs with both types or transformers were connected to the C64 Power Tester.
2. The 9VAC was loaded with different combinations of load resistors
3. For each combination, the output current and voltage were measured

### 2.3.2. Block VC 16/1/9

Rated Power: 16VA

IOUT | UOUT | Diagram
0.00A | 11.34V
0.30A | 10.94V
0.39A | 10.82V
0.44A | 10.74V
0.47A | 10.68V
0.53A | 10.60V
0.59A | 10.57V
0.60A | 10.55V
0.70A | 10.38V
0.80A | 10.28V
0.99A | 10.00V
1.04A | 9.87V
1.12A | 9.61V

### 2.3.3. BREVE TUFVASSONS TEZ10/D230/9V

Rated power: 10VA

IOUT | UOUT | Diagram
0.00A | 11.73V
0.30A | 11.01V
0.39A | 10.81V
0.47A | 10.60V
0.51A | 10.51V
0.58A | 10.34V
0.59A | 10.30V
0.68A | 10.06V
0.77A | 9.83V
0.93A | 9.41V
0.98A | 9.31V

## 2.4. Thermal testing

The thermal testing was conducted with the electronic load set to 1.00A for the 5VDC and a load resistor of 10Ω/10W connected to the 9VAC. The 121GW and 89 IV multimeters were equipped with K-type thermo couples, which were first attached to the transformer and the AC/DC module with Kapton tape (Figure 4, Figure 5).

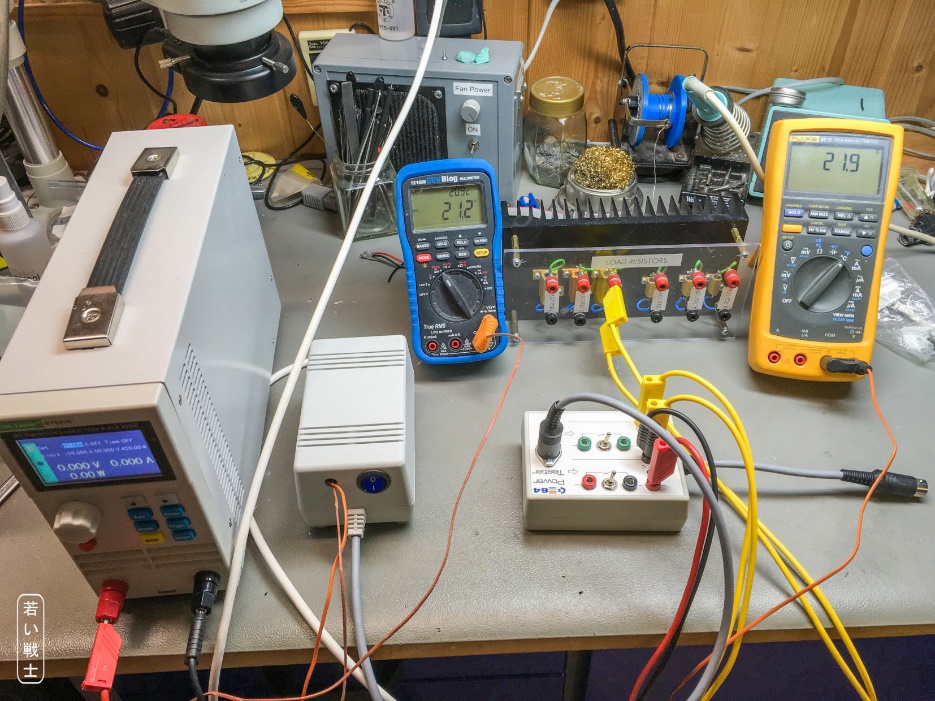
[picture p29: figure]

Figure 4: Setup for thermal testing

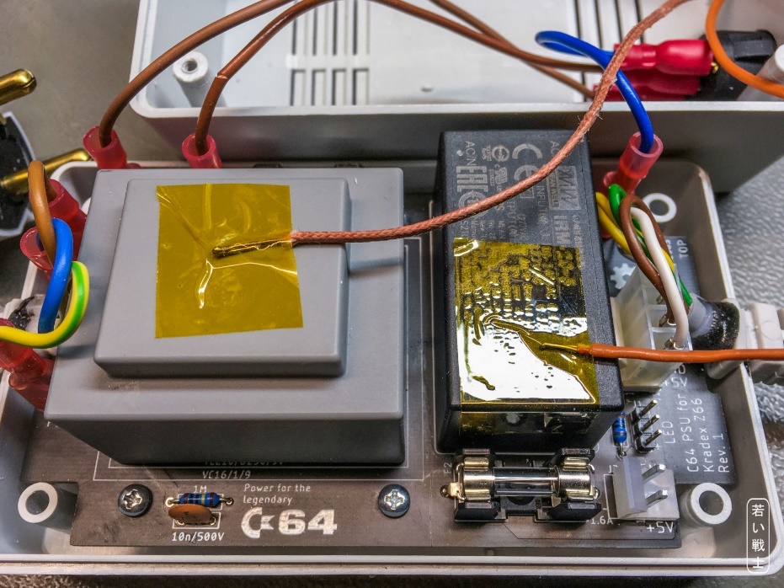
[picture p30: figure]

Figure 5: Position of the thermo couples for the 1st test run

The DUT was switched on and was running for a couple of hours until both temperatures settled to a maximum value. The transformer was the hottest of both components. In a second run, the 2nd thermo couple was placed on the case in the middle of the top shell (Figure 6).

With the TEZ10/D230/9V, a temperature of 65.6°C on the transformer surface and 48.6°C inside the case was finally reached (Figure 7). The ambient temperature was 22°C (initial reading from 121GW). The transformer is rated for a maximum ambient temperature of 60°C, the IRM-20-5 is rated 70°C, the MPM-10-5 is rated 85°C.

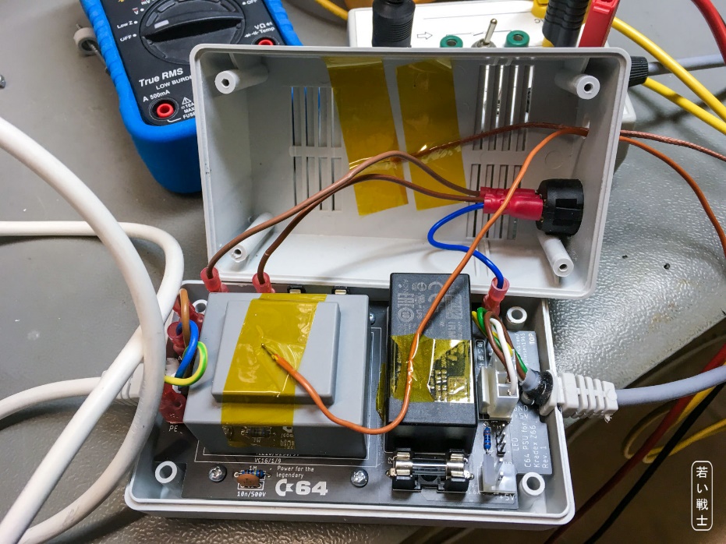
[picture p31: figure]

Figure 6: Thermo couple placement for the final run

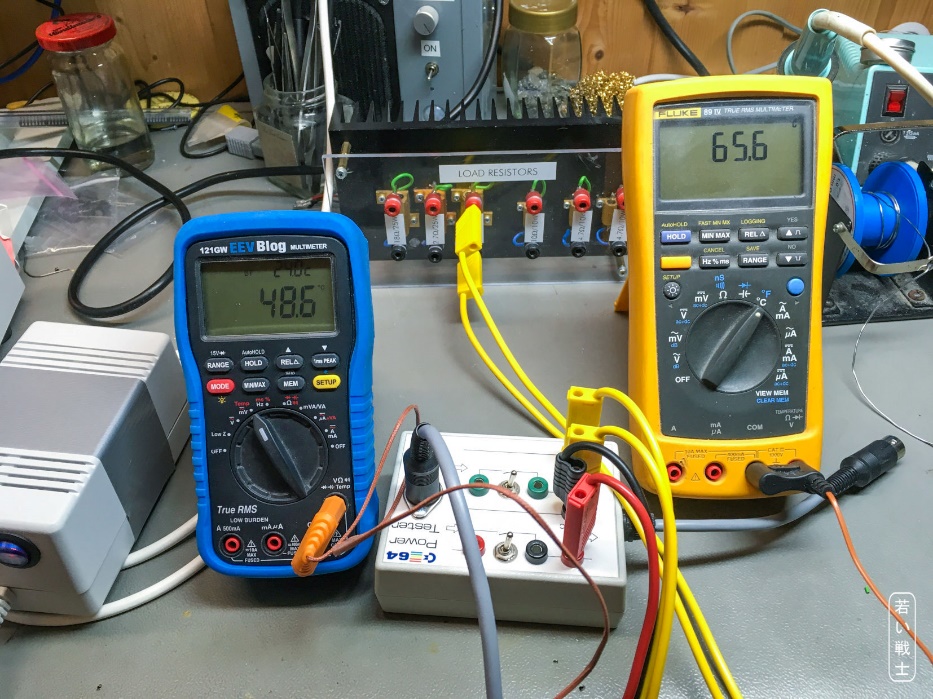
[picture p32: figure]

Figure 7: Final temperatures with the TEZ10/D230/9V transformer

The test was also executed with the Rev. 0 prototype that has the Block VC 16/1/9 transformer. The ambient temperature was 22°C. After about 5 hours, the temperatures settled to 44.9°C inside the case and 52.2°C on the transformer. The transformer is rated for an ambient temperature of 40°C, which is exceeded by almost 5°C.

## 2.5. Real Life Testing

Finally, the PSU (with the IRM-20-5) was tested with a real C64. ASSY 250407 was chosen due to the highest power consumption (827mA @ 5VDC, 778mA @ 9VAC) and the power hungry Ultimate II+ disk drive (and much more) emulator was connected. A C64 test software was loaded from the Ultimate II+ and executed (without a test harness) for 6 hours.

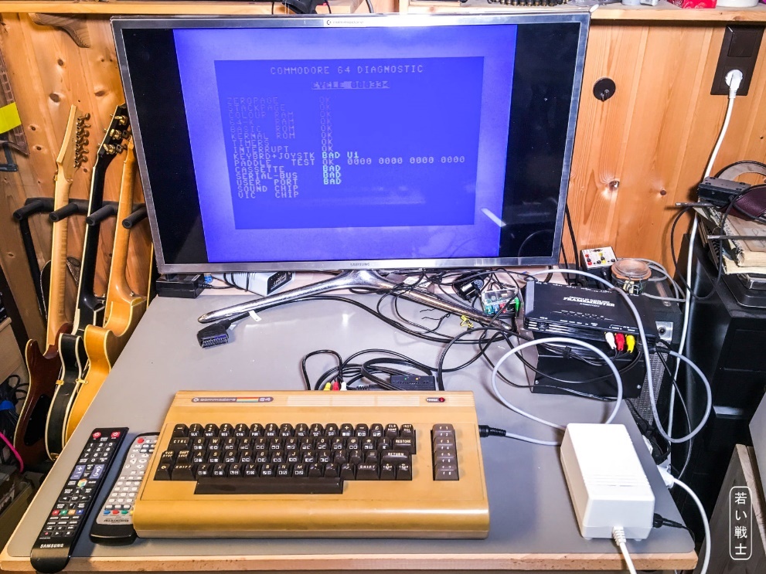
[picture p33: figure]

Figure 8: Setup of the real-life test

The software was running without any problems. It did not hook up.

Further, the Pi1541 (disk drive emulator) was powered by the PSU for another 3 hours. The C64 and the Pi1541 were active all the time, while demos have been played back. Again, no problems were found.

After this time had elapsed, the temperatures were measured with a surface probe.

Locaction | Temperature
Top of case | 33°C
Top of transformer | 50°C
Top of AC/DC module | 56°C

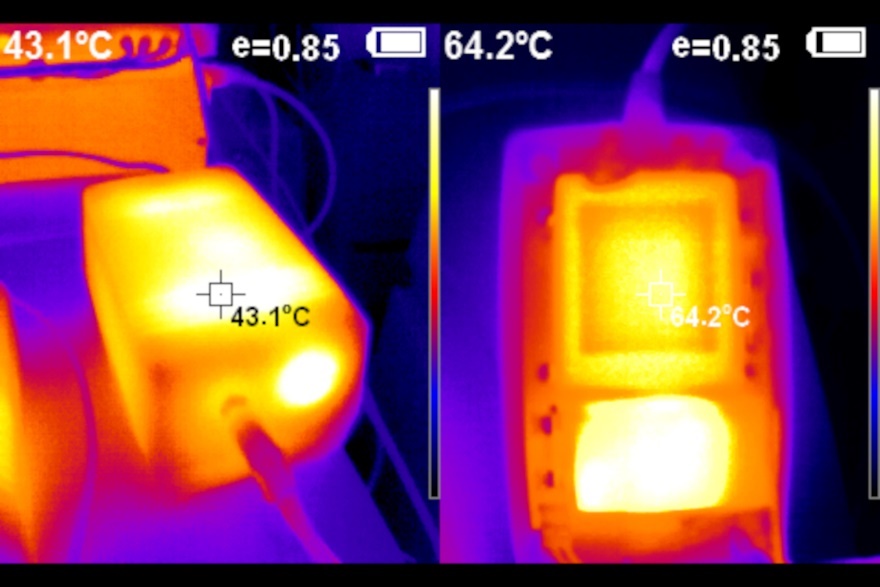
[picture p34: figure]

Figure 9: FLIR images of the outside and inside of the PSU

Note: the temperature measurement requires setting the proper emissivity (e) for each material, so the displayed temperatures (Figure 9) are not accurate.

# 3. Conclusion

## 3.1. AC/DC Modules

Both modules work. The IRM-20-5 has a higher maximum output current (4A) and a higher ripple (which is not considered critical). The MPM-10-5 is more expensive, has only 2A output current and a lower ripple. It is approved for medical equipment, which explains the higher price.

## 3.2. Transformers

Both transformers work. At the current consumption of about 0.75A (ASSY 250405 and 250425), the output voltage of the 16VA transformer is about 0.5V higher than the one of the 10VA transformer. This will lead to 0.4W more power dissipation in the linear voltage regulators and an increased temperature. It is not critical for most C64s, except some of the early ASSY320298, which do not have a heat sink installed on the 7805 5V lineal regulator.

The VC 16/1/9 (16VA) has a much lower rating for the maximum ambient temperature (40°C) than the 10VA transformer TEZ10/D230/9V (60°C). The current drawn while the thermal testing is higher than the current drawn by a C64. The 16VA variant stays cooler, but still the maximum temperature is exceeded by 5°C. It is probably not critical, but definitely not recommended.

Thus, the TEZ10/D230/9V is the preferred type.

## 3.3. Final verdict

Both tested revisions are fully functional. The VC 16/1/9 transformer is not recommended.

C64PSU-Z66_Test.docx 18.02.2022 20:08 Drafted by Sven Petersen Page 2 of 2 Doc.-No.: 160-6-02-01

C64PSU-Z66_Test.docx 18.02.2022 20:08 Drafted by Sven Petersen Page 1 of 1 Doc.-No.: 000-6-00-00

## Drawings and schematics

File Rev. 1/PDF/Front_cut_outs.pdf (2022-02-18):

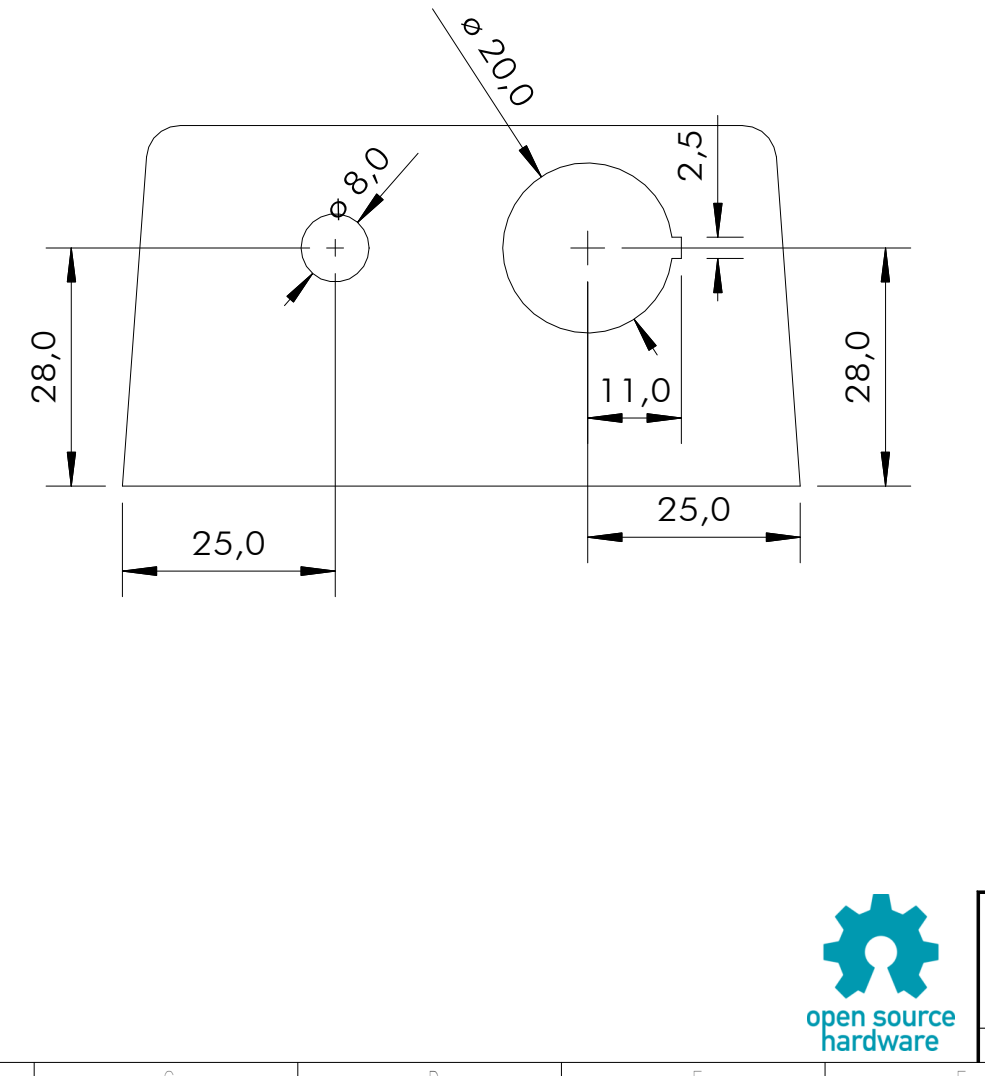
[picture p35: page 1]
Doc.-No.: 160-3-01-01; Date: 08.02.2022 21:23; Sven Petersen; case for the power switch etc.; Front.SKF

Title:
Front cutouts of the Z66

Draft.: Sven Petersen
File:
Rev.: 1

http://github.com/svenpetersen1965

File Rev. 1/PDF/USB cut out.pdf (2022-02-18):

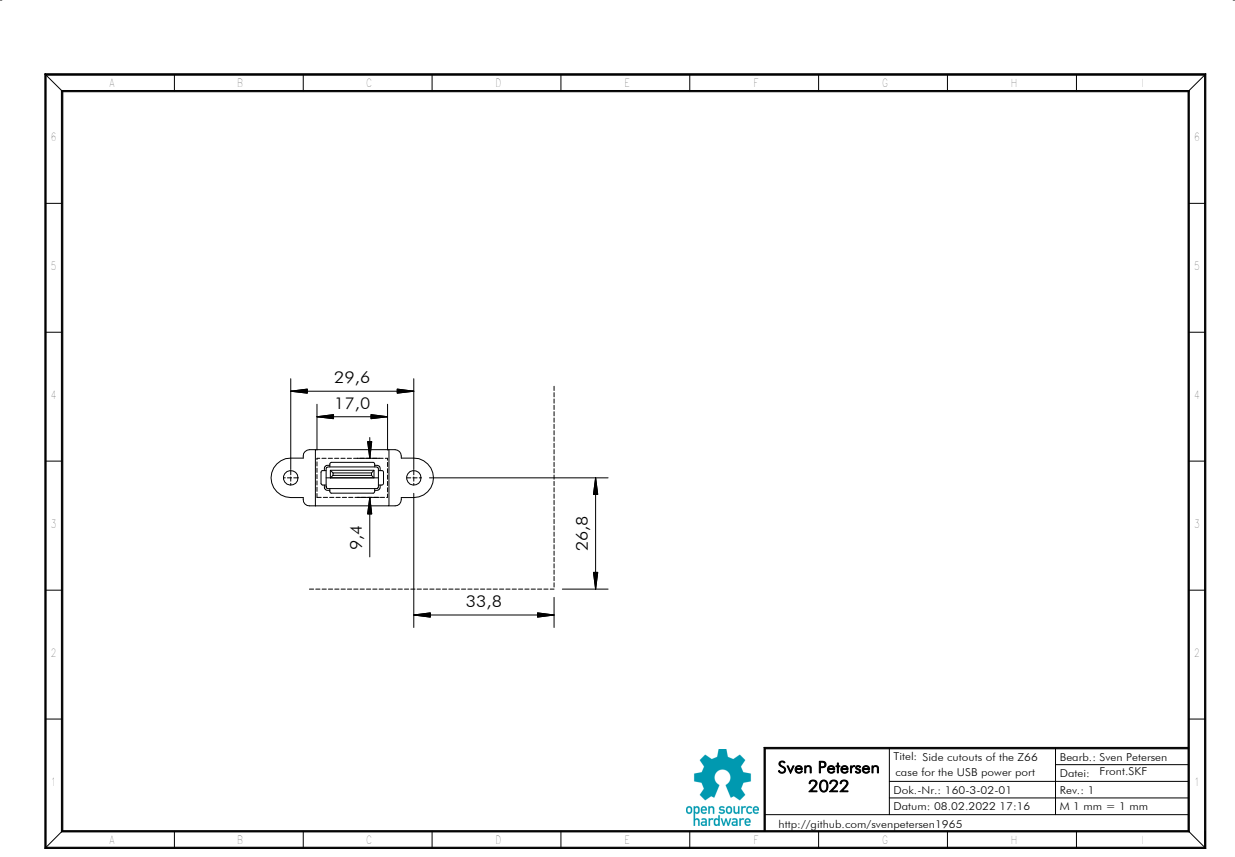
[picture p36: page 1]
Dok.-Nr.: 160-3-02-01; Datum: 08.02.2022 17:16; Sven Petersen; case for the USB power port; Front.SKF

Titel:
Side cutouts of the Z66

Bearb.: Sven Petersen
Datei:
Rev.: 1

http://github.com/svenpetersen1965

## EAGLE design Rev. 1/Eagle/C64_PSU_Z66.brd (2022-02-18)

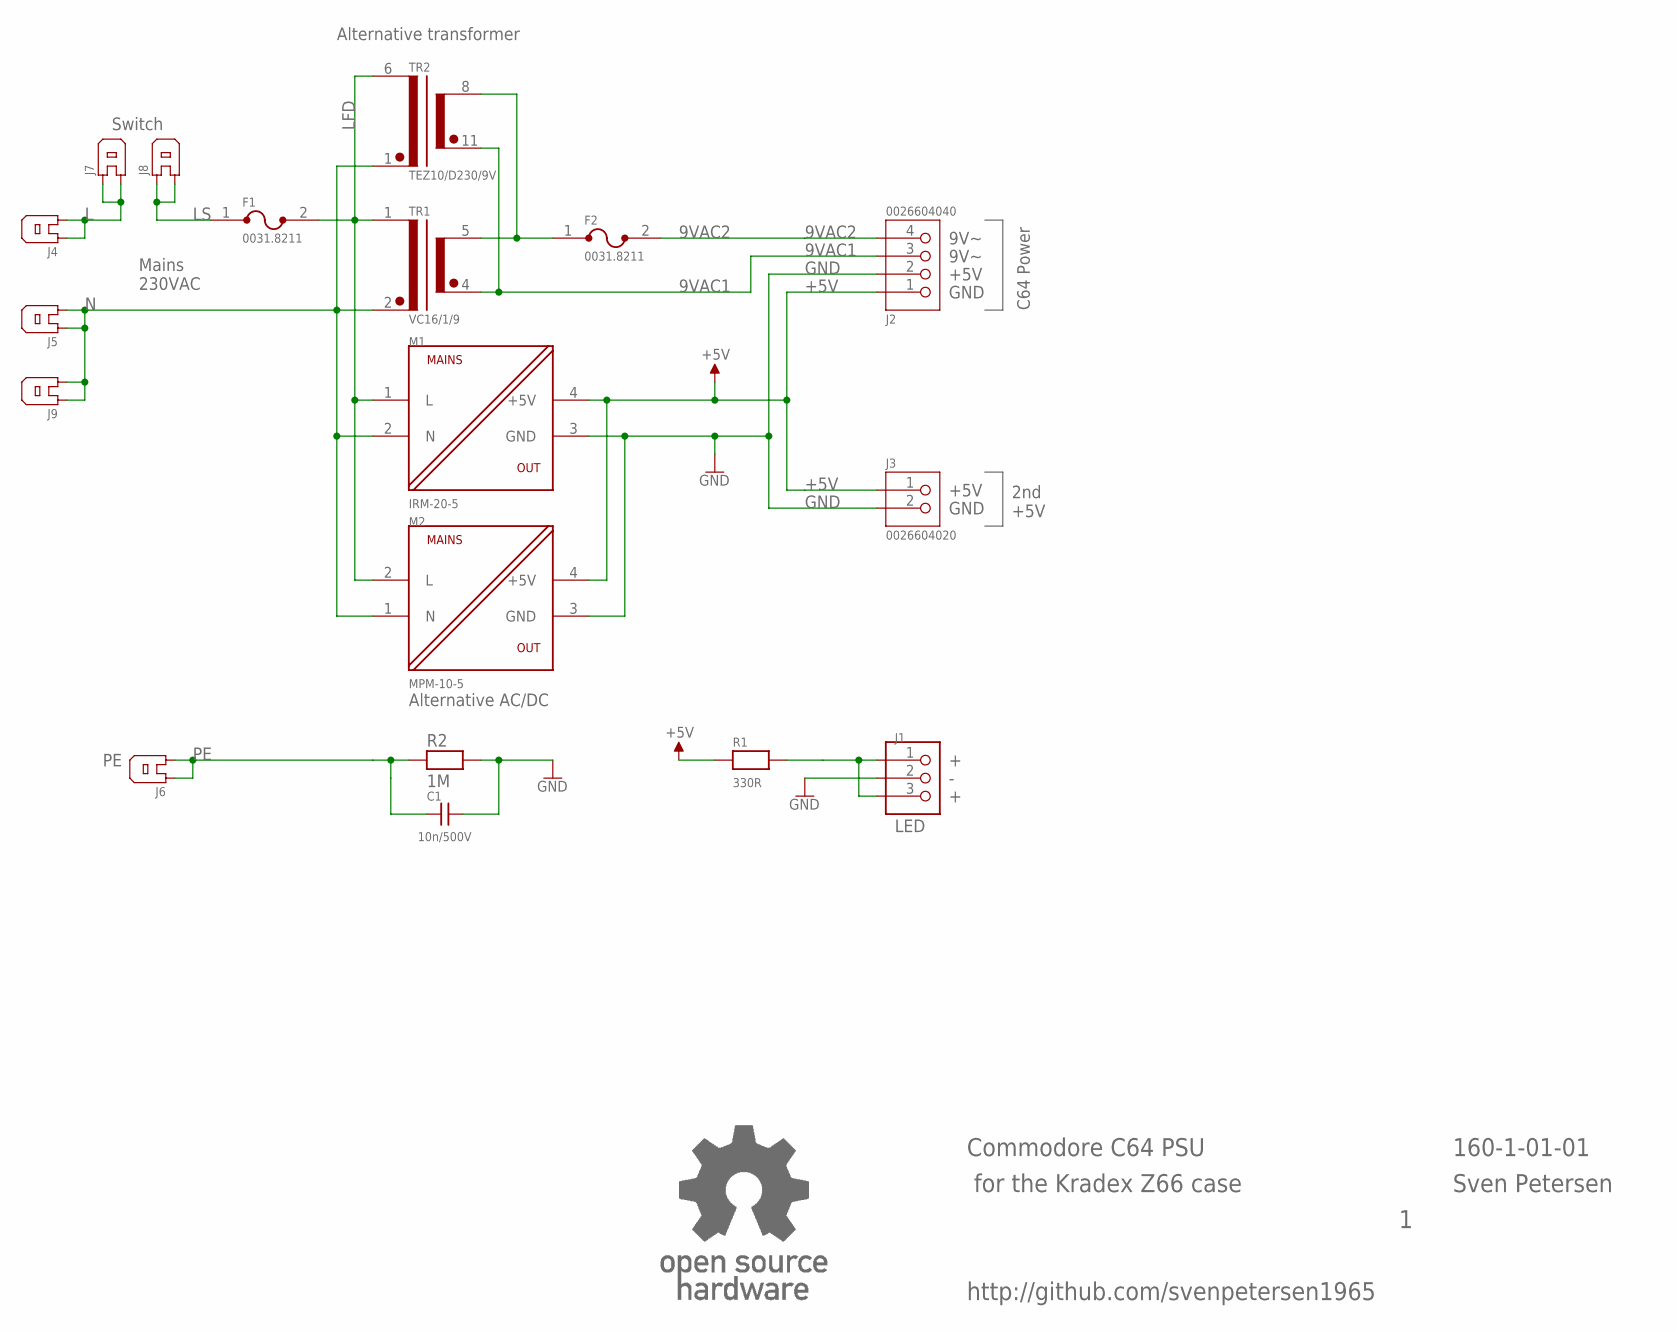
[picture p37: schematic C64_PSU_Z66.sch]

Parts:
C1: 10n/500V; C-5
F1, F2: 0031.8211
J1: PINHD-1X3; 1X03
J2: 0026604040; SPOX_3.96_4P
J3: 0026604020; SPOX_3.96_2P
J4, J5, J6, J7, J8, J9: FLA6,3
M1: IRM-20-5; IRM-5-20
M2: MPM-10-5; MPM10
R1: 330R; R-10
R2: 1M; R-10
TR1: VC16/1/9
TR2: TEZ10/D230/9V; TEZ10
U$8: OPEN_SOURCE_HW; OPENHW

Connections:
9VAC1: J2.3, TR1.4 (SEC12), TR2.11 (SEC12)
9VAC2: F2.2, J2.4
+5V: J2.1, J3.1, M1.4 (+5V), M2.4 (+5V), R1.1
GND: C1.2, J1.2, J2.2, J3.2, M1.3 (GND), M2.3 (GND), R2.2
L: J4.1, J4.2, J7.1, J7.2
LFD: F1.2, M1.1 (L), M2.2 (L), TR1.1 (PRI1), TR2.6 (PRI1)
LS: F1.1, J8.1, J8.2
N: J5.1, J5.2, J9.1, J9.2, M1.2 (N), M2.1 (N), TR1.2 (PRI2), TR2.1 (PRI2)
unnamed: J1.1, J1.3, R1.2
unnamed: F2.1, TR1.5 (SEC11), TR2.8 (SEC11)
PE: C1.1, J6.1, J6.2, R2.1

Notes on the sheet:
Alternative transformer
Alternative AC/DC
LED
9V~
+5V
GND
Mains 230VAC
Commodore C64 PSU
Sven Petersen
160-1-01-01
http://github.com/svenpetersen1965
for the Kradex Z66 case
C64 Power
2nd +5V
Switch

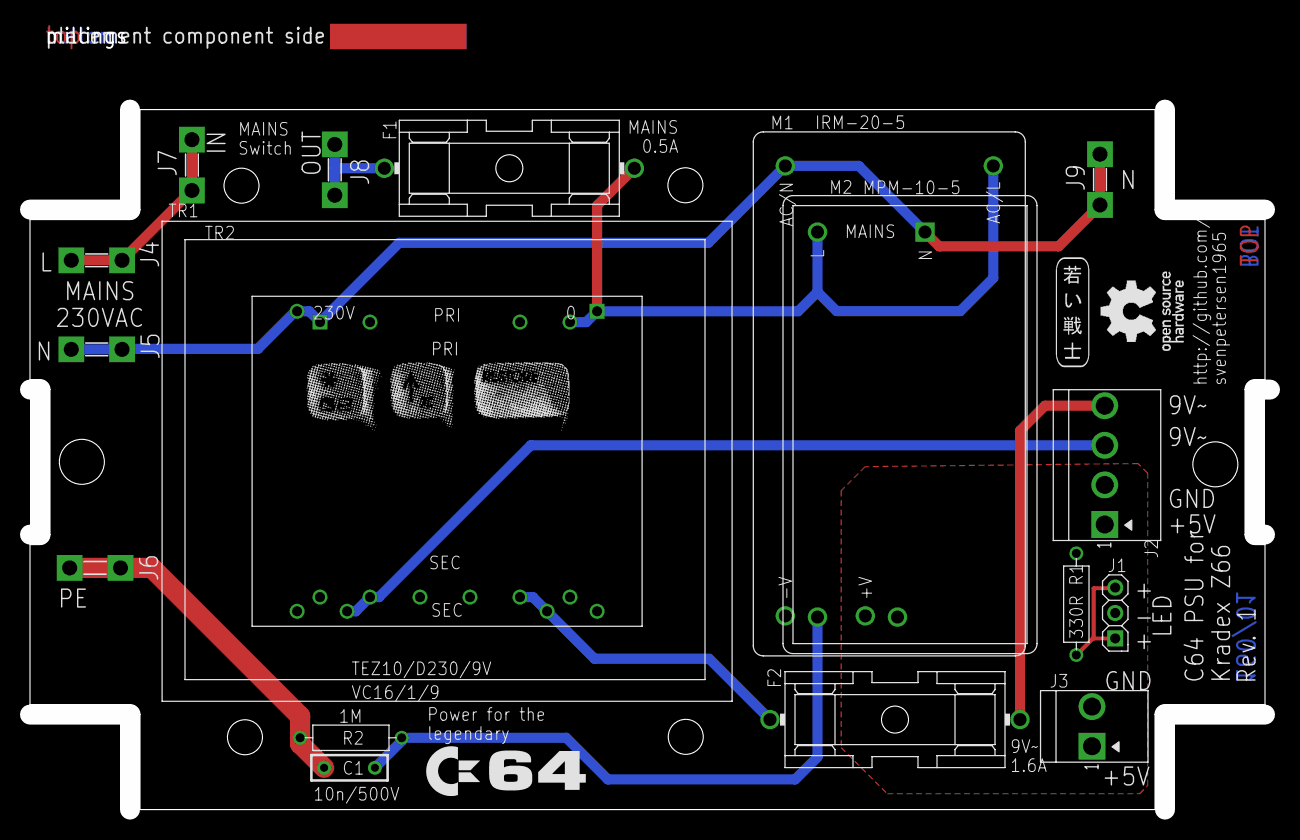
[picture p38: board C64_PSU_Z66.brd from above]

Board: 2 copper layers, 123.5 x 70.0 mm, 25 parts (0 on the bottom side), 11 nets.

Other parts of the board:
U$7: Z66
U$9: C64_LOGO
U$10: PCB-TITLE/
U$11: 2LAYER
U$12: C64_KEYS
U$13: SVEN_TAG
